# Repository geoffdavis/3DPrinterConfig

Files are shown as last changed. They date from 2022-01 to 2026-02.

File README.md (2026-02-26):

# 3DPrinterConfig

My 3D Printers Configuration backup.

## Active Printers

| | [Voronica](voronica) | [Hodad](hodad) |
|---|---|---|
| **Model** | Voron 2.4 350mm (FYSETC kit, 2.4R2 mods) | Voron v0.2r1 (Formbot kit) |
| **Mainboard** | FYSETC Spider 2.2 | BTT SKR Pico |
| **Toolhead** | Mellow SB2040 (CAN) | BTT EBB36 (CAN) |
| **Hotend** | Slice Mosquito Magnum | E3D Revo Voron |
| **Firmware** | [Klipper](https://www.klipper3d.org/) | [Klipper](https://www.klipper3d.org/) |
| **Web UI** | Fluidd / Mainsail | Mainsail |

## Retired Printers

| [MPMD](mpmd) | [Pruscilla](pruscilla) | [Smurf](smurf) | [Limewire](limewire) |
|---|---|---|---|
| Monoprice MiniDelta (stock board) | Prusa i3 MK3S (sold) | Monoprice MiniDelta w/ SKR Pico (cannibalized) | Rook MK1 (retired) |

## Guide

This firmware repo is based loosely on [willngton/3DPrinterConfig](https://github.com/willngton/3DPrinterConfig).

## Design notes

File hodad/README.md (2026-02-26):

# Hodad - Voron v0.2r1

## Overview

* Formbot Voron v0.2R1 kit.
* BTT SKR Pico mainboard
* BTT EBB36 CAN toolhead
* Revo Voron hotend with higher watt heater
* LDO Orbiter 2.0 extruder with ministealthorbiter toolhead
* Mainsail web UI
* Raspberry Pi 4 (BTT Pi from kit died)

## Modifications

* [EBB36 CAN toolhead][ebb36]
* Daylight on a matchstick, using Pico hotend heater port
* Revo VORON with higher watt heater
* Full-width [DIN rail mount][DIN-mount] for Raspberry Pi, SKR Pico, and Mellow Fly UTOC
* DS18B20 one-wire thermistor hooked up to BTT Pi to work around lack of extra Analog thermistor ports on the SKR Pico (no longer necessary with EBB36 but it's already installed.)
* Mapleleafmaker's [Stealth handles][stealth-handles] on the sides
* loicloic's [Voron V0/V0.1/V0.2 Compact Handles][compact-handles] - single one only, on front of tophat to help open it.
* Mapleleafmaker's Daylight on a [Matchstick diffusers][matchstick-diffusers]
* Mapleleafmaker's [Upper Rear Bowden Inlet for BTT SFS 2.0](https://www.printables.com/model/408745-v0-upper-rear-bowden-inlet-urbi)
* MandicReally's [Voron Hex Mid panel][mr-hex-mid-panel]
* LDO Orbiter 2.0 extruder with ministealthorbiter toolhead
* Raspberry Pi 4 instead of BTT Pi

## Notes

I nuked the Neopixel on the SKR Pico, but the digital IO pin still works and external neopixels connected to the 3-pin connector seem to work fine.

The magnets that ship with the Formbot kit are not strong enough to hold the door closed through all of the foam and plastic between them. I had some stronger ones that _just_ barely hold the door closed now.

The BTTPi died - several USB ports are fried, the mini CAN bridge seems to have flaked out. Using a RPi4 now. See also my old [notes for working with the BTT Pi.](docs/BTT_Pi.md)

## Links

* [Ballistic Tech's very helpful docs](https://github.com/SrgntBallistic/Formbot-V0)
* [Helpful build log](https://www.teamfdm.com/forums/topic/2178-my-first-voron-v02r1-formbot-kit/)

## Procedures

### Auto-hotspot

For taking the printer for a walk.

Source: [Raspberry Pi Auto-hotspot script](https://www.raspberryconnect.com/projects/65-raspberrypi-hotspot-accesspoints/183-raspberry-pi-automatic-hotspot-and-static-hotspot-installer)

Credentials are here: https://start.1password.com/open/i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

### Firmware updates

See [Firmware Update](docs/Firmware_Update.md) docs for instructions on how to update Klipper on this thing.

### Bed leveling

The front-panel menu has a bed-leveling routine on it. It's a manual `bed_screws_adjust` process.

### Bed Z offset

```gcode
G28
G1 X55 Y55 F6000
Z_ENDSTOP_CALIBRATE
```

[ebb36]: https://github.com/bigtreetech/EBB
[DIN-mount]: https://www.printables.com/model/381062-voron-v01-v02-din-rail-board-mounting-system
[stealth-handles]: https://www.printables.com/model/481575-v0-stealth-handles
[compact-handles]: https://www.printables.com/model/108428-voron-v0v01v02-compact-handles
[matchstick-diffusers]: https://www.printables.com/model/408214-matchstick-diffusers
[mr-hex-mid-panel]: https://thangs.com/designer/MandicReally/3d-model/Voron%20Hex%20Mid%20Panel%20-%20Accent%20your%200.2%21-960156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

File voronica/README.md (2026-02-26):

# Voronica - Voron 2.4 350mm

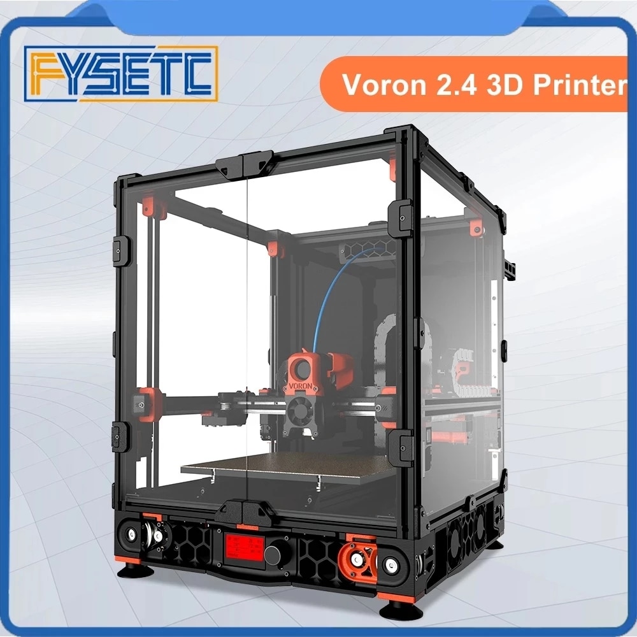
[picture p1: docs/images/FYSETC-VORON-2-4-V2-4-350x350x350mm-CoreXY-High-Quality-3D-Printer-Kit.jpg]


FYSETC Voron 2.4 Kit with 2.4R2 mods applied. Slice Mosquito Magnum hotend, option to switch to Revo. SB2040 CAN bus toolhead.

## Overview

* FYSETC Spider 2.2 mainboard (USB-CAN bridge mode)
* Mellow SB2040 CAN bus toolhead
* Slice Mosquito Magnum hotend (Revo V6 alternate)
* Bondtech CHT nozzles
* Happy Hare MMU2S multi-material unit
* Fluidd / Mainsail web UI

## Modifications

* Slice Mosquito Magnum with Bondtech CHT nozzles
* Alternate - E3D Revo V6 option
* [Mellow RP2040 CAN bus toolhead](CANBUS/SB2040/)
* [FYSETC CAN-bus Expander for Spider](https://www.fysetc.com/products/fysetc-canbus-expander-module-for-spider-board)
* Finger ducting in wiring bay [similar to LDO kit](https://docs.ldomotors.com/en/voron/voron2/wiring_guide_rev_c)
* Parts-binned filtered AC inlet - Interpower 83510031. I designed a [custom skirt to hold it](STL/Voron%20Power%20Inlet%20-%20Interpower%20Filtered/README.md).

## Electronics Bay

Here's the electronics bay as of October of 2023.

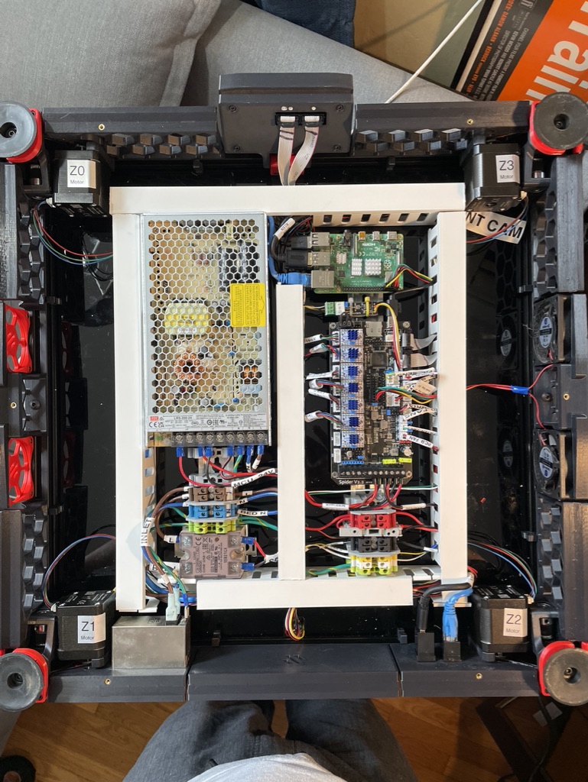
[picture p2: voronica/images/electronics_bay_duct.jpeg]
Bottom Electronics Bay with finger ducting


### Mainboard

FYSETC Spider 2.2

Rear view of the Spider board showing the pin mapping to the MCU:

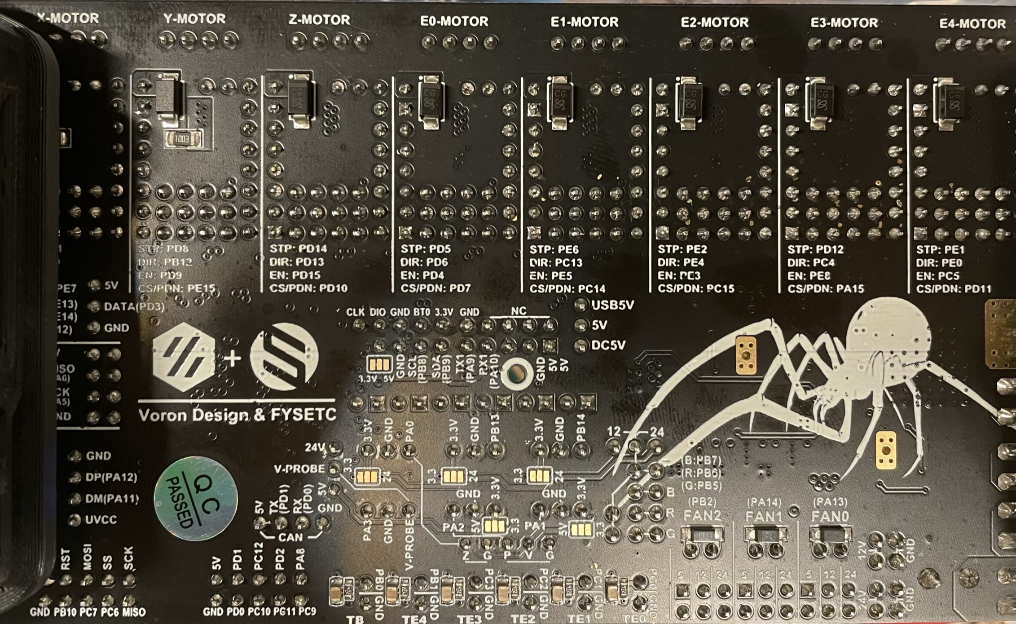
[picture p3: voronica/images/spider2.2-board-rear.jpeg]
FYSETC Spider 2.2 Mainboard Rear


There's a [mapping file of pins to symbolic names](klipper/spider_aliases.cfg) in the klipper configuration.

## Notes

Parts all printed on Pruscilla.

## Links

* [Klipper Spider Config](https://github.com/VoronDesign/Voron-2/blob/Voron2.4/firmware/klipper_configurations/Spider/Voron2_Spider_Config.cfg)
* [Klipper Install and Update Helper](https://github.com/th33xitus/kiauh)
* [FYSETC Voron 2 Repo](https://github.com/FYSETC/FYSETC-Voron-2)
* [FYSETC Kit BOM](https://github.com/FYSETC/FYSETC-Voron-2/blob/main/BOM.md)
* [FYSETC Spider Pinout](https://github.com/FYSETC/FYSETC-SPIDER/blob/main/Spider_V2.2_Pinout.pdf)
* [Voron Sourcing Guide](https://vorondesign.com/sourcing_guide?model=V2.4)
* [Mellow SB2040 install](https://www.teamfdm.com/forums/topic/851-install-canboot-on-sb2040/#comment-5785)

## Procedures

### Toolhead changes

When replacing the hotend, the effective difference between the nozzle probe point and the TAP sensor can change. This was noted when replacing the Printables version of the Mosquito hotend holder with the Bondtech one that Slice recommended.

Do this with the `PROBE_CALIBRATE` command.

### Gantry maintenance

During initial assembly, plain old loctite Blue thread locker was used, but somewhat inconsistently. Several bolts worked their way loose as a result and the gantry got racked a bit, and the Z axis bearings came loose.

The bolts were replaced and VC3 thread-locker (as recommended by Annex Engineering) was applied to all of the bolts in the gantry.

#### De-racking and squaring

Following the procedures detailed in the Voron [V2 Gantry Squaring](https://docs.vorondesign.com/build/mechanical/v2_gantry_squaring.html) documentation, I worked through reassembling the frame.

One problem noted was that the front idler bolts holding the pulleys were a bit loose, and this was adding mechanical noise. This is the big vertical bolt in the idler. The A side in particular was very loose.

#### Belt tensioning

Fiddling with belt tension is best done with a relative tension gauge, followed by `BELTS_SHAPER_CALIBRATION`

Per notes above, the idler pulley bolts in the front adjustable idlers need to be snug. Otherwise, weird vibrations result that can't be backed out with belt tension.

### Firmware updates

See [Firmware Update](docs/Firmware_Update.md) docs for instructions on how to update Klipper on this thing.

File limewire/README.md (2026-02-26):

# Limewire (RETIRED)

## About

Rook Mk1 with take-offs from Voron v0 and the MPMD. **Retired.**

## Components

* SKR Pico
* Raspberry Pi 3
* Motors from MPMD
* Power supply: Meanwell 150 Watt from formbot kit
* Bed: from Formbot v0 kit
* Bearings, rails: West3D Rook Kit

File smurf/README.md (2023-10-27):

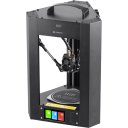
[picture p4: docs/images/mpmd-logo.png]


# MPMD "Smurf"

Monoprice MiniDelta v1 2019-era with the higher resolution stepper motors.
Converted to an SKR Pico 1.0 with a RPi 3
<br />
<br />

## Modifications

* Binder Clip Bed Mod
* Wham-Bam Flex Build plate
* Crap catchers on towers
* Stiffer spring rate extruder - CR-10 clone
* Klipper Firmware
* E3D Revo hotend with custom effector based on [ksihota's MPMD E3D V6 Effector](https://www.thingiverse.com/thing:4855333), modified for Revo micro heatsing
* SKR Pico 1.0 Main board
* Waveshare 4.3 inch DSI touchscreen for raspberry pi
* higher wattage power supply in raised base, [slobrohim's Monoprice Mini Delta Power Supply Base](https://www.thingiverse.com/thing:4786403). Had to attack it with some plastic cutters to get the raspberry pi to fit. Using the Meanwell LRS-150-12 instead of slobrohim's recommended LRS-150-24, as I didn't want to upgrade the heater pad on the bed to 24VDC. It's a small enough printer that I don't see the need to go 24V, and this way I can print off a car battery if I want later.
* BTT Smart Filament sensor
* [LED ring light at top of case.](https://www.thingiverse.com/thing:4284397) run off of the SKR Pico Neopixel bus.

## Notes

I could not get the stock optical end-stops to work at all. I may have nuked them by sending them 5V instead of 3.3 v. I tried another set from the MP Mini Delta V2 and had similar lack of luck.

Attemped using the TMC2209 virtual endstops with the printed endstop replacements from https://www.prusaprinters.org/prints/113166-mpmd-frame-mods

Found that it wasn't as reliable as I'd like - even with endstop phase turned on, tuning the virtual endstops was an exercise in frustration. Switched to Lerge optical endstops using custom parts found on the Facebook group for the MPMD:

* https://www.facebook.com/groups/mpminideltaowners/permalink/3501827253166069/
* https://www.facebook.com/groups/mpminideltaowners/permalink/3500216336660494/
* https://www.facebook.com/groups/mpminideltaowners/permalink/3487387884610006/

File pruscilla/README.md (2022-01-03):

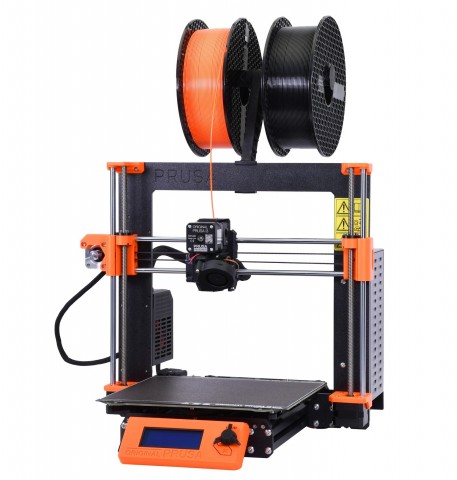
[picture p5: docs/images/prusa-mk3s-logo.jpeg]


# Pruscilla

Pruscilla i3 MK3S
<br />
<br />

## Modifications

* MK3S+ hotend
* "Custom" fried fan port on Einsy
* MMU2S
* PrintedSolid Enclosure
* Pi4 with TFT and Octoprint/Octodash

# Guides

## Prusa Firmware with Pin Remap

I keep somehow frying the hotend thermistor port on multiple Einsy rambo boards. There's a way to remap to an unused port by custom compiling your own firmware.

### Requirements:

* Debian/Ubuntu Linux x86_64. Doesn't work on MacOS, doesn't work on Raspbian

* Ubuntu VM (I use the one on my main workstation, Obelisk)

* Check out [firmware] repository.

### Build

#### Step 1 - checkout/update source
*NOTE* You might need to `git clean -dxf` an existing checkout in order to get the build to work right.

#### Step 2 - Set up the firmware variant and modify pin definitions

##### Step 2a: Set the firmware variant
Set the firmware variant to the correct one.

cp Firmware/variants/

##### Step 2b: Change the pin definitions
Apply the following diff, swapping TEMP_0_PIN and TEMP_1_PIN. TEMP_0_PIN should be 0, while TEMP_1_PIN should be 1.

```
geoff@obelisk-ubuntu:~/src/Prusa-Firmware$ git diff
diff --git a/Firmware/pins_Einsy_1_0.h b/Firmware/pins_Einsy_1_0.h
index b3841a59..74de5ea9 100755
--- a/Firmware/pins_Einsy_1_0.h
+++ b/Firmware/pins_Einsy_1_0.h
@@ -59,10 +59,12 @@
 #define TEMP_BED_PIN         2 //A2
 
 #define HEATER_0_PIN         3 //PE5
-#define TEMP_0_PIN           0 //A0
+//#define TEMP_0_PIN           0 //A0
+#define TEMP_0_PIN           1 //A1 as A0 is fried
 
 #define HEATER_1_PIN        -1
-#define TEMP_1_PIN           1 //A1
+//#define TEMP_1_PIN           1 //A1
+#define TEMP_1_PIN           0 //A0 (this pin is unused)
 
 #define HEATER_2_PIN        -1
 #define TEMP_2_PIN          -1
```

#### Step 3 - build
Run `./build.sh`

Resulting bin file is in `lang/firmware.hex`

[firmware]: https://github.com/prusa3d/Prusa-Firmware.git

#### Step 4 - Upload the file

You can do this from the octoprint host. Use `scp` to put it somewhere on octoprint:

```
scp lang/firmware.hex pi@pruscilla:
```

Then, use `avrdude` to upload it from the octoprint host:

```
avrdude -v -p atmega2560 -c wiring -P /dev/ttyACM0 -b 115200 -D -U flash:w:firmware.hex:i
```

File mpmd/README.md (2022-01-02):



## MPMD

Monoprice MiniDelta v1 2019-era with the higher resolution stepper motors.
<br />
<br />

### Modifications

* Binder Clip Bed Mod
* Borosilicate Glass Bed
* Crap catchers on towers
* Stiffer spring rate extruder
* Klipper Firmware using stock mainboard

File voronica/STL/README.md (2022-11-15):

# STLs

Custom STL files used during the build.

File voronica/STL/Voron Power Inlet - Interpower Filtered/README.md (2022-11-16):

Voron 2.4 Power inlet skirt for Interpower filtered power inlet
===

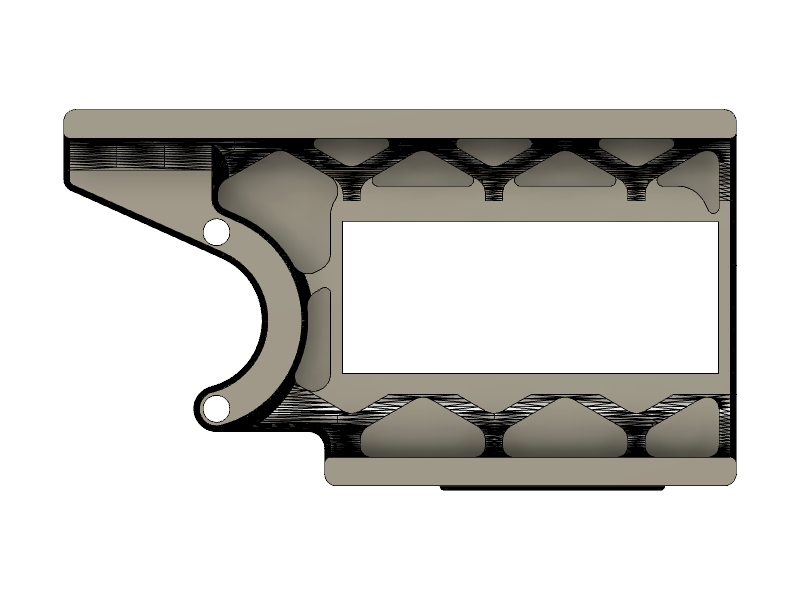
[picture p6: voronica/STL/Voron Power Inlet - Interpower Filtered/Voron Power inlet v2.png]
Voron Interpower power inlet skirt v2


Application
---

Fits an [Interpower](https://interpower.com) panel-mount snap fit IEC power inlet.

Designed for P/N [83510031](https://www.interpower.com/cgi-bin/ic.cgi/p35form.p?w_part=83510031)

Should also fit P/N [83510071](https://www.interpower.com/cgi-bin/ic.cgi/p35form.p?w_part=83510071)

License
---

GPLv3 (same as upstream Voron 2.4 STLs)
See [LICENSE](LICENSE) for details.

Author
---

Geoff Davis <geoff@geoffdavis.com>

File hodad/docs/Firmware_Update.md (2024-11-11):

# Hodad Klipper Firmware Update Procedures

## SKR Pico

This MCU is connected via UART, updates must be done over USB.

### Step 1: Get unit in DFU mode
Connect USB-A-M to USB-C-M cable between host and MCU
Install boot jumper, then press reset button. Boot jumper is in the middle of the board, to the right of the power LED as mounted in the printer (closer to the TMC driver heatsink with the bigtreetech logo)
Verify that the device shows up in lsusb:

```
pi@hodad:~/klipper $ lsusb | grep RP2
Bus 001 Device 015: ID 2e8a:0003 Raspberry Pi RP2 Boot
```

### Step 2: Build firmware

Per [https://github.com/bigtreetech/SKR-Pico/tree/master/Klipper] set:
* Enable extra low-level configuration options
* Micro-controller Architecture = `Raspberry Pi RP2040`
* Communication interface = `Serial (on UART0 GPIO1/GPIO0)`

Run `make clean`
Run `make -j3`

### Step 3: Flash firmware

*NOTE* this requires that the unit be placed in DFU mode per step 1, above.

Run `make flash FLASH_DEVICE=2e8a:0003`

### Step 4: Remove boot jumper

Remove the boot jumper to the right of the power LED. Optionally, press the reset button (white button towards the top of the board as mounted in the printer)

## v0 Display board

This unit is connected via USB.

Docs: [https://github.com/VoronDesign/Voron-Hardware/blob/master/V0_Display/Documentation/Setup_and_Flashing_Guide.md]

### Step 1 - DFU mode

Install the boot jumper and reset the board. This will put the board into DFU mode.

The boot jumper is located on the top rear of the v0 display PCB, and is a real pain to access.

1. Remove the bottom panel - 2mm hex driver, round or square
2. Remove the v0 display with a round head 2 mm hex driver
3. install the boot jumper
4. Press reset
5. Verify it shows up in `lsusb`
```
pi@hodad:~/klipper $ lsusb | grep DFU
Bus 001 Device 022: ID 0483:df11 STMicroelectronics STM Device in DFU Mode
```

### Step 2 - Build firmware

This controller has very limited flash memory, and a full-blow Klipper instance won't fit. Be sure to uncheck most of the Optional features as shown below.

Firmware settings:

* Enable extra low-level configuration options
* Micro-controller Architecture: `STMicroelectronics STM32`
* Processor model: `STM32F042`
* Bootloader offset: `No bootloader`
* Clock reference: `internal clock`
* Communication interface `USB (on PA9/PA10)`
* Optional features:
  a. Check `Support GPIO "bit-banging" devices`
  b. Check `Support LCD devices`
  c. Check `Support external sensor devices`
  d. Uncheck `Support lis2dw 3-axis accelerometer`
  e. Uncheck `Support ldc1612 eddy current sensor`
  f. Uncheck `Support HX711 and HX717 ADC chips`
  g. Uncheck `Support ADS 1220 ADC chip`
  e. Uncheck `Support software based I2C "bit-banging"`
  f. Check `Support software based SPI "bit-banging"`

Run `make clean`

### Step 3 - flash firmware

Run `make flash FLASH_DEVICE=0483:df11`

### Step 4 - Remove boot jumper

Remove the boot jumper and press the reset button

Verify that you now see one or more stm32f042x6 devices in lsusb, and that `/dev/serial/by-id/usb-Klipper_stm32f042x6_05001A000643564E32313720-if00` appears in `/dev/serial/by-id`

h5. Re-install display and bottom cover

Curse at no-drop nuts that still drop anyway.

This is best done with the printer completely inverted so that the nuts in the extrusion don't keep sliding around.

## Klipper Expander

Very similar to the V0 Display, same controller. Same recommended firmware settings.

[https://github.com/VoronDesign/Voron-Hardware/blob/master/Klipper_Expander/Documentation/Setup_and_Flashing_Guide.md]

### Step one - DFU mode

1. Install the boot jumper. Boot jumper is between the USB port and the DC input terminals.
2. Press the reset button. The reset button is next to the "n" in the "Voron Design" silkscreen.
3. Verify it shows up in `lsusb`
```
pi@hodad:~/klipper $ lsusb | grep DFU
Bus 001 Device 022: ID 0483:df11 STMicroelectronics STM Device in DFU Mode
```

*NOTE* as this is the same chip as the V0 display, make sure you only have one device in DFU mode at a time.

### Step two - compile firmware

Firmware settings (identical to V0 Display):

* Enable extra low-level configuration options
* Micro-controller Architecture: `STMicroelectronics STM32`
* Processor model: `STM32F042`
* Bootloader offset: `No bootloader`
* Clock reference: `internal clock`
* Communication interface `USB (on PA9/PA10)`
* Optional features:
  a. Check `Support GPIO "bit-banging" devices`
  b. Check `Support LCD devices`
  c. Check `Support external sensor devices`
  d. Uncheck `Support lis2dw 3-axis accelerometer`
  e. Uncheck `Suppert software based I2C "bit-banging"`
  f. Check `Support software based SPI "bit-banging"`

### Step 3 - flash firmware

Run `make flash FLASH_DEVICE=0483:df11`

### Step 4 - remove jumper and reset board

Verify no devices in DFU mode show in the `lsusb` output

Verify that the MCU shows up as `/dev/serial/by-id/usb-Klipper_stm32f042x6_08002300134330534E373720-if00`

## EBB36 Can Toolhead board

This unit has [katapult](https://github.com/Arksine/katapult) (formerly "Can-boot") installed. KB-3D has [decent instructions for installing katapult on a fresh board](https://wiki.kb-3d.com/en/home/btt/voron/BTT_EBB36), though you will need to replace all references to `Can-boot` with `katapult`.

NOTE: once `katapult`/`Can-boot` is installed, the device will no longer show up in the output of `lsusb` if you connect it directly to the Pi with a USB cable. It will show up however if you put the device into DFU mode.

The instructions below assume that you've already installed `katapult` and are just upgrading the `klipper` firmware.

### Step 1 - Verify CAN is working

Press the reset button on the back of the EBB36 toolhead board.

Run the following:

```
~/CanBoot/scripts/flash_can.py -i can0 -q
```

You should see output similar to:

```
pi@hodad:~ $ ~/katapult/scripts/flash_can.py -i can0 -q
Resetting all bootloader node IDs...
Checking for Katapult nodes...
Detected UUID: 12676b53cab4, Application: Klipper
Query Complete
```

Step 2: Compile firmware

```
cd ~/klipper
make menuconfig
```

Firmware settings:

* `Enable extra low-level configuration options`
* Micro-controller Architecture `STMicroelectronics STM32`
* Processor model: `STM32G0B1`
* Bootloader: `8KiB bootloader`
* Clock Reference: `8 MHz crystal`
* Communication interface: `CAN bus (on PB0/PB1)`
* CAN bus speed: `1000000` -- note that this must match setting in `/etc/network/interfaces.d/can0`
* GPIO pins to set at micro-controller startup: none

```
make clean
make -j3
```

### Step 3: Flash firmware over canbus

The UUID of the board is `2aab98198ff0` (November 2024 was `12676b53cab4` originally)

```
python3 ~/katapult/scripts/flash_can.py -i can0 -f ~/klipper/out/klipper.bin -u 2aab98198ff0
```

If all goes well, it should look like this:

```
python3 ~/katapult/scripts/flash_can.py -i can0 -f ~/klipper/out/klipper.bin -u 2aab98198ff0
Sending bootloader jump command...
Resetting all bootloader node IDs...
Attempting to connect to bootloader
Katapult Connected
Protocol Version: 1.0.0
Block Size: 64 bytes
Application Start: 0x8002000
MCU type: stm32g0b1xx
Verifying canbus connection
Flashing '/home/pi/klipper/out/klipper.bin'...

[##################################################]

Write complete: 14 pages
Verifying (block count = 427)...

[##################################################]

Verification Complete: SHA = F836B5FC5E1BD91779D80950095C73C06F06593C
Flash Success
```

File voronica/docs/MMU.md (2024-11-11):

# MMU Notes

## Purge volumes with CLEAN_NOZZLE

From Voron Discord #ercf_questions:

Dendrowen (mr. Blobifier) — 01/06/2024 11:57 AM
Yeah, I'm having problems with the retraction of filametrix, so I only retract 15mm which means around 40mm is still there. I have a purge command that purges 40mm + the flushing volumes

CLEAN_NOZZLE FINAL_RETRACT={retraction_length[0]} PURGE_LEN={40 + first_flush_volume + second_flush_volume} 

I use OrcaSlicer and have my flushing multiplier set to 0.40.

https://github.com/moggieuk/Happy-Hare/blob/variables/doc/gcode_preprocessing.md

https://github.com/moggieuk/Happy-Hare/blob/main/doc/slicer_setup.md#---start-g-code

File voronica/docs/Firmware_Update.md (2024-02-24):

# Voronica Firmware Update Procedures

One of the annoying things about Klipper is that updating the MCUs isn't an easy task. Each MCU has to be compiled individually, and this can clobber your firmware configuration files if you're not careful.

In the klipper-build directory, I keep some of the menuconfig output for the various MCUs.

## Spider

Board must be in DFU in order to flash.

### Step one - stop klipper
1. `sudo service klipper stop`

### Step two - put Spider board in DFU mode

1. Install jumper between BT0 and 3.3V - USE PLASTIC TWEEZERS or power down printer, or be a hero and use long metal needlenose and try not to short anything.
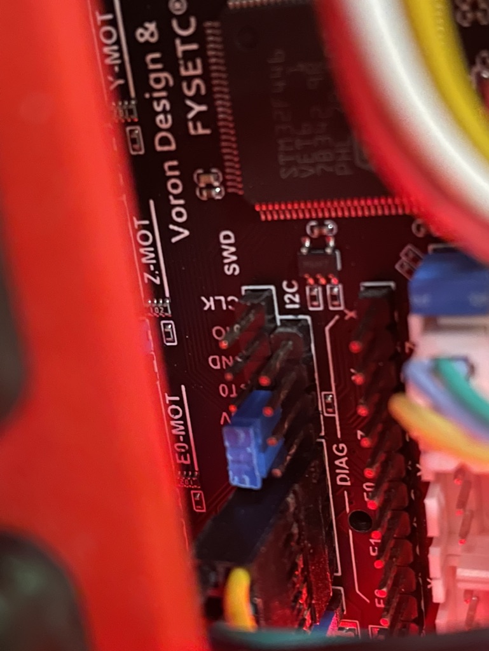
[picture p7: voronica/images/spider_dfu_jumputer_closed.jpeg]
Jumper Closed

1. Press reset button on right hand side by Pi (below white zip tie in below picture)
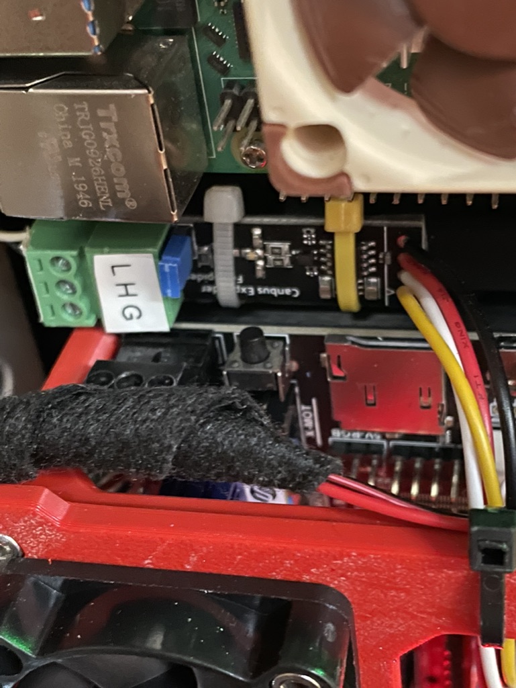
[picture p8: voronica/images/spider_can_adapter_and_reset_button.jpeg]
Reset button

1. Verify the spider shows up in `lsusb` output. Should be something like:

    ```none
    ~/klipper  ‹master*› $ lsusb | grep DFU
    Bus 001 Device 005: ID 0483:df11 STMicroelectronics STM Device in DFU Mode
    ```

### Step three - build and flash klipper

1. Perform the build and flash.

    ```bash
    cd ~/klipper
    FLASH_DEVICE="0483:df11"
    KCONFIG_DIR="${HOME}/printer_data/config/klipper-build"
    _kc="${KCONFIG_DIR}/config.spider"
    make clean KCONFIG_CONFIG="${_kc}"
    make menuconfig KCONFIG_CONFIG="${_kc}"
    make -j4 KCONFIG_CONFIG="${_kc}"
    make flash FLASH_DEVICE="${FLASH_DEVICE}" KCONFIG_CONFIG="${_kc}"
    ```

    a. If the settings get clobbered, use:

      * Enable extra low-level configuration options
      * Microcontroller Arch: `STMicroelectronics STM32`
      * Processor model: `STM32F446`
      * Bootloader offset: `32KiB bootloader`
      * Clock Reference: `12 MHz crystal`
      * Communication interface: `USB to CAN bus bridge (USB on PA11/PA12)`
      * CAN bus interface: `CAN bus (on PD0/PD1)`
      * CAN bus speed 1000000 (1Mbit, defaults to 500000)
      * GPIO Pins to set at micro-controller startup: NONE (make sure it's empty)

### Step four - take board out of DFU mode

1. Remove jumper - USE PLASTIC TWEEZERS
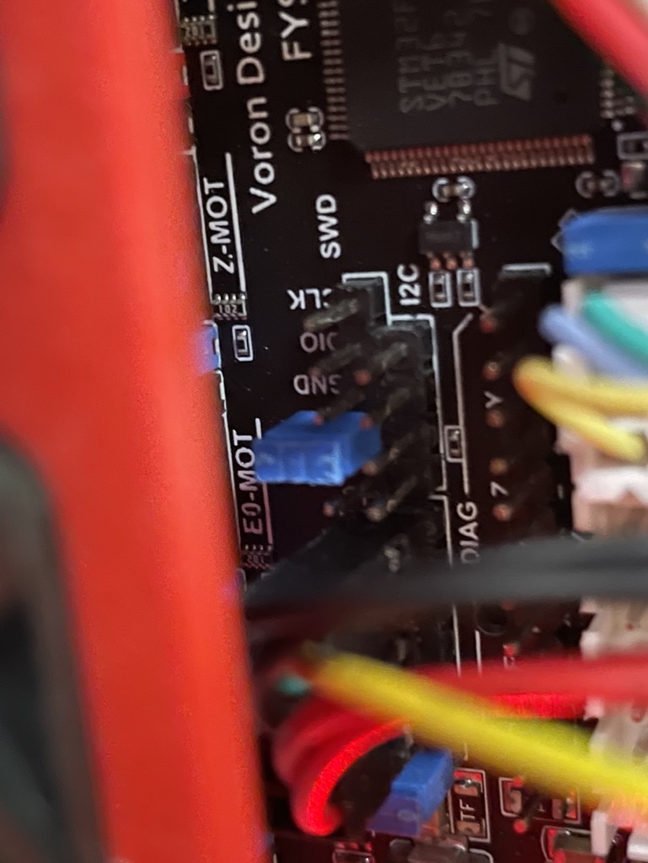
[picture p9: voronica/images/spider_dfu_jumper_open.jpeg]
Jumper open
Jumper in open position: 
1. Press reset button (below white zip tie in picture)
Reset button
1. Verify board shows up in `lsusb` output again

    ```none
    ~/klipper  ‹master*› $ lsusb | grep CAN
    Bus 001 Device 008: ID 1d50:606f OpenMoko, Inc. Geschwister Schneider CAN adapter
    ```

### Step five - restart Klipper

1. Start klipper

NOTE: depending on the state of the USB to CAN adapter, the SB2040

## SB2040 Toolhead via CanBoot

This toolhead was originally configured using the CanBoot instructions from this document: [SB2040 and the curious case of disappearing firmware](https://docs.google.com/document/d/1yaRNuQxDxqgijE8YeJ2r9tUZgJZ4tXXjmrAiFyAfsek/edit)

Once installed, the CanBoot firmware rarely, if ever, needs to be updated again.

NOTE: to get the SB2040 into DFU mode, you need to stop klipper first, then power cycle the toolhead. The asiest way to do that at the moment is to pull the fuse in the underside electronics bay.

### Step One - stop klipper

1. `sudo service klipper stop`

### Step Two - get board into DFU mode

1. Power cycle toolhead by opening and closing the fuse panel on the bottom.
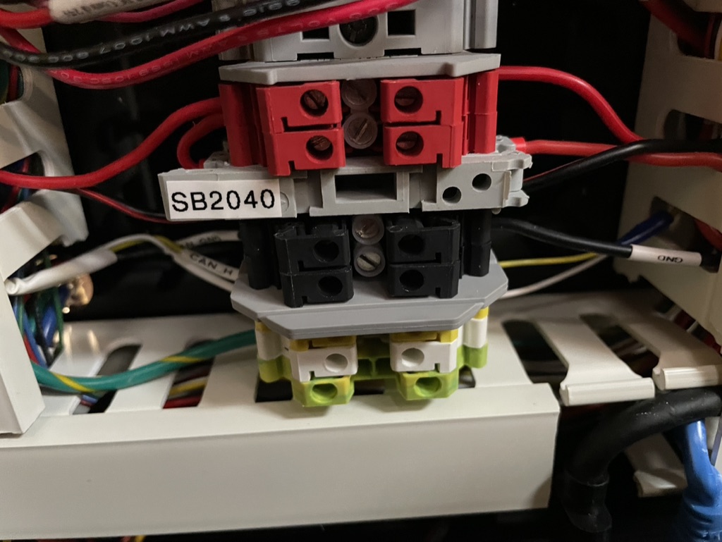
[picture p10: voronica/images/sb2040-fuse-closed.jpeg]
SB2040 Fuse
  Closed fuse: 
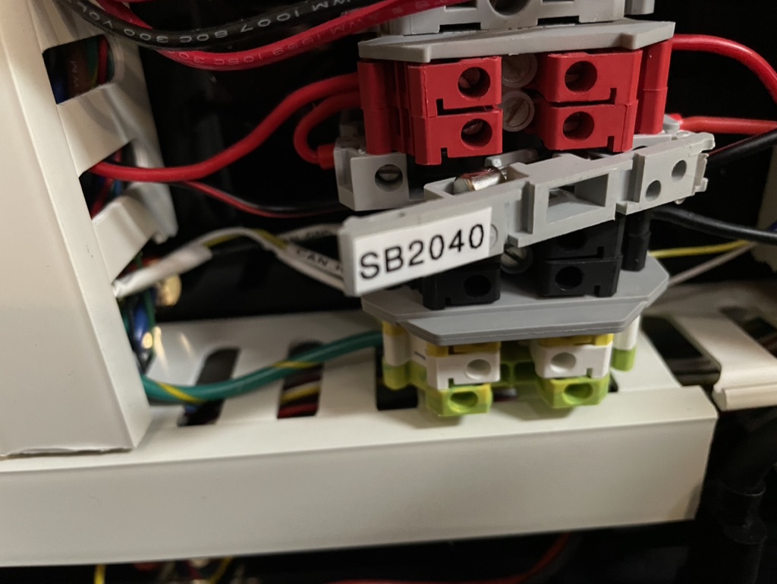
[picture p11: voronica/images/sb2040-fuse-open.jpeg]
SB2040 Fuse Open
  Open fuse: 

### Step 3 - Build and Flash

1. Find the CAN ID:

    ```bash
    cd ~/CanBoot
    ../klippy-env/bin/python ../klipper/scripts/canbus_query.py can0
    ```

    Should show something like:

    ```none
     ~/CanBoot/ [master] ../klippy-env/bin/python ../klipper/scripts/canbus_query.py can0
    Found canbus_uuid=f6f9ce8939ef, Application: Klipper
    Total 1 uuids found
    ```
1. Perform the build and flash.

    ```bash
    cd ~/klipper
    CANBUS_UUID=f6f9ce8939ef
    KCONFIG_DIR="${HOME}/printer_data/config/klipper-build"
    _kc="${KCONFIG_DIR}/config.sb2040-canboot"
    make clean KCONFIG_CONFIG="${_kc}"
    make menuconfig KCONFIG_CONFIG="${_kc}"
    make -j4 KCONFIG_CONFIG="${_kc}"
    ./lib/canboot/flash_can.py -u $CANBUS_UUID -v -f ./out/klipper.bin
    ```

    a. If the settings get clobbered, use:
      * Extra options: enabled
      * Microcontroller Arch: `Raspberry Pi RP2040`
      * Bootloader offset: `16KiB bootloader`
      * Flash chip W25Q080 with CLKDIV 2
      * Communication interface `CAN bus`
      * CAN bus speed: `1000000` (1Mbit, defaults to 500000)
      * CAN RX gpio number: `4`
      * CAN TX gpio number: `5`
      * GPIO pins to set at startup: `gpio24`

### Step 4 - Restart Klipper
1. Start klipper and make sure that the system sees the MCU: `sudo service klipper start`

## Raspberry Pi host

This MCU lets you trigger relays and other GPIOs. I'm not currently using any of that functionality, but I am using it for the host load average calculations and other side benefits.

### Step 1 - Stop Klipper

1. Stop klipper `sudo service klipper stop`

### Step 2 - Build and flash
1. Perform the build and flash.

    ```bash
    cd ~/klipper
    KCONFIG_DIR="${HOME}/printer_data/config/klipper-build"
    _kc="${KCONFIG_DIR}/config.rpi"
    make clean KCONFIG_CONFIG="${_kc}"
    make menuconfig KCONFIG_CONFIG="${_kc}"
    make -j4 KCONFIG_CONFIG="${_kc}"
    make flash KCONFIG_CONFIG="${_kc}"
    ```

    a. If the settings get clobbered, use:

      * Microcontroller Arch Linux process

### Step 3 - Restart Klipper

1. Start klipper `sudo service klipper start`

## TinyFan

Extra fan controller - https://github.com/Gi7mo/TinyFan

### Step 1 - DFU Mode

1. Stop klipper `sudo service klipper stop`
1. Press boot and reset simultaneously on the tinyfan rp2040 daughterboard.
    You should now see the following in `lsusb` output:
    ```Bus 001 Device 018: ID 2e8a:0003 Raspberry Pi RP2 Boot```

### Step 2 Perform the build

    ```bash
    cd ~/klipper
    KCONFIG_DIR="${HOME}/printer_data/config/klipper-build"
    _kc="${KCONFIG_DIR}/config.tinyfan"
    make clean KCONFIG_CONFIG="${_kc}"
    make menuconfig KCONFIG_CONFIG="${_kc}"
    make -j4 KCONFIG_CONFIG="${_kc}"
    ```

    a. If the settings get clobbered, use:

      * Enable extra low-level configuration options
      * Micro-controller Architecture: `Raspberry Pi RP2040`
      * Flash chip: `GENERIC_03H with CLKDIV 4`
      * Communication interface: `USB`
      * USB ids: leave default
      * GPIO pins at startup: EMPTY

### Step 3 - flash the device

```bash
sudo mount /dev/sda1 /mnt && \
sudo cp out/klipper.uf2 /mnt && \
sudo umount /mnt
```

### Step 4 - Reset the board

Press the reset button on the daughterboard

Verify that you can now see in `lsusb`:

```
Bus 001 Device 020: ID 1d50:614e OpenMoko, Inc. rp2040
```

### Step 5 - Restart klipper

1. Start klipper `sudo service klipper start`

## TradRack SKR Mini E3 V2.0

This device has Katapult installed, because mini sd card firmware updates are for chumps.

Katapult instructions: [https://klipper.discourse.group/t/flashing-klipper-friendly-bootloader-on-btt-skr-mini-e3-v2/10977]

### Step 1 - Stop Klipper

### Step 2 - put board in USB bootloader mode

Double press the reset button on the mainboard.

### Step 3 - Compile Klipper

```bash
cd ~/klipper
KCONFIG_DIR="${HOME}/printer_data/config/klipper-build"
_kc="${KCONFIG_DIR}/config.tr"
make clean KCONFIG_CONFIG="${_kc}" && \
make menuconfig KCONFIG_CONFIG="${_kc}" && \
make -j4 KCONFIG_CONFIG="${_kc}"
```

If the settings get clobbered, use:

* **Enable** extra low-level configuration options
* Micro-controller Architecture: `STMicroelectronics STM32`
* Bootloader offset: `8KiB bootloader` - *NOTE this is different than the Voron default of `28KiB` due to `katapult` being in place!!*
* Clock reference: `8 MHz crystal`
* Communication interface: `USB (on PA11/PA12)`
* GPIO pins: `!PA14` - Don't forget to set this, the board won't boot otherwise

### Step 4 - flash the board

Note that the device must be in bootloader mode per Step 2.

1. Run the flash command:

  ```bash
  # Below command only worked the first time with the deployer.bin
  make flash \
    KCONFIG_CONFIG="${_kc}" \
    FLASH_DEVICE=/dev/ttyACM3
  #
  # --or--
  #
  # this worked with the double-press of the reset button
  make flash \
    KCONFIG_CONFIG="${_kc}" \
    FLASH_DEVICE=/dev/serial/by-id/usb-katapult_stm32f103xe_30FFDA054E4E353717730551-if00
  ```

### Step 5 - restart klipper

1. Reset the board to get it out of DFU.
1. Start klipper: `sudo service klipper start`

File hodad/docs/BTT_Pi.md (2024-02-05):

# BigTreeTech Pi Notes

## Dallas 1-wire

* DS18B20 on BigTreeTech Pi: https://gist.github.com/mdvorak/2fccca3fa9f76f5a2e11e567797c76d6
* One-wire kernel module compilation instructions: https://github.com/pstolarz/w1-gpio-cl#readme

## BTT Pi Pins

Overflow sensors are hooked into the BTT Pi 24-pin header

| Pin # | Pin Name | Description |
| ----- | --- | --- |
| 1 | 3.3V | DS18B20 VCC |
| 3 | PC3 | N/C (reserved for ADXL Header) |
| 5 | PC0 | N/C (reserved for ADXL Header) |
| 7 | PC7 (GPIO71) | DS18B20 One-wire data |
| 9 | GND | DS18B20 Ground |
| 11 | PC14 | NC |
| 13 | PC12 | NC |
| 15 | PC10 | NC |
| 17 | 3.3V | BTT SFS2.0 VCC |
| 19 | PH7 (GPIO231) | BTT SFS2.0 Switch Sensor |
| 21 | PH8 (GPIO232) | BTT SFS2.0 Motion Sensor |
| 23 | PH6 (GPIO23) | NC |
| 25 | GND | BTT SFS2.2 GND |
| 27 | PC2 (GPIO66) | N/C (reserved for ADXL Header) |
| 29 | PC4 (GPIO68) | N/C (reserved for ADXL Header) |
| 31 | PI5 (GPIO261) | MOSFET 4 |
| 33 | PI14 (GPIO270) | MOSFET 3 |
| 35 | PC6 (GPIO70) | MOSFET 2 |
| 37 | PC15 (GPIO79) | MOSFET 1 |
| 39 | GND | MOSFET Input Ground |
| 2 | 5V | From SKR Pico 5V |
| 4 | 5V | From SKR Pico 5V |
| 6 | GND | From SKR Pico GND |
| 8 | TX | To SKR Pico RX |
| 10 | RX | To SKR Pico TX |
| 12 | PC13 | NC |
| 14 | GND | NC |
| 16 | PC11 | NC |
| 18 | PC9 | NC |
| 20 | GND | NC |
| 22 | PG13 | NC |
| 24 | PG12 | NC |
| 26 | PI9 | NC |
| 28 | PI10 (Blue, EEPROM?) | NC |
| 30 | GND | NC |
| 32 | PI6 | NC |
| 34 | GND | NC |
| 36 | PG11 | NC |
| 38 | PH4 | NC |
| 40 | PC8 | NC |

###
```none
biqu@hodad:~/3DPrinterConfig$ sudo cat /sys/kernel/debug/pinctrl/300b000.pinctrl/pinmux-pins
Pinmux settings per pin
Format: pin (name): mux_owner|gpio_owner (strict) hog?
pin 0 (PA0): device 5030000.ethernet function emac1 group PA0
pin 1 (PA1): device 5030000.ethernet function emac1 group PA1
pin 2 (PA2): device 5030000.ethernet function emac1 group PA2
pin 3 (PA3): device 5030000.ethernet function emac1 group PA3
pin 4 (PA4): device 5030000.ethernet function emac1 group PA4
pin 5 (PA5): device 5030000.ethernet function emac1 group PA5
pin 6 (PA6): device 5030000.ethernet function emac1 group PA6
pin 7 (PA7): device 5030000.ethernet function emac1 group PA7
pin 8 (PA8): device 5030000.ethernet function emac1 group PA8
pin 9 (PA9): device 5030000.ethernet function emac1 group PA9
pin 10 (PA10): device 5002c00.i2c function twi3 group PA10
pin 11 (PA11): device 5002c00.i2c function twi3 group PA11
pin 12 (PA12): device soc:pwm5@0300a000 function pwm5 group PA12
pin 64 (PC0): UNCLAIMED
pin 65 (PC1): UNCLAIMED
pin 66 (PC2): UNCLAIMED
pin 67 (PC3): UNCLAIMED
pin 68 (PC4): UNCLAIMED
pin 69 (PC5): UNCLAIMED
pin 70 (PC6): UNCLAIMED
pin 71 (PC7): GPIO 300b000.pinctrl:71
pin 72 (PC8): UNCLAIMED
pin 73 (PC9): UNCLAIMED
pin 74 (PC10): UNCLAIMED
pin 75 (PC11): UNCLAIMED
pin 76 (PC12): UNCLAIMED
pin 77 (PC13): UNCLAIMED
pin 78 (PC14): UNCLAIMED
pin 79 (PC15): GPIO 300b000.pinctrl:79
pin 80 (PC16): UNCLAIMED
pin 160 (PF0): device 4020000.mmc function mmc0 group PF0
pin 161 (PF1): device 4020000.mmc function mmc0 group PF1
pin 162 (PF2): device 4020000.mmc function mmc0 group PF2
pin 163 (PF3): device 4020000.mmc function mmc0 group PF3
pin 164 (PF4): device 4020000.mmc function mmc0 group PF4
pin 165 (PF5): device 4020000.mmc function mmc0 group PF5
pin 166 (PF6): GPIO 300b000.pinctrl:166
pin 192 (PG0): device 4021000.mmc function mmc1 group PG0
pin 193 (PG1): device 4021000.mmc function mmc1 group PG1
pin 194 (PG2): device 4021000.mmc function mmc1 group PG2
pin 195 (PG3): device 4021000.mmc function mmc1 group PG3
pin 196 (PG4): device 4021000.mmc function mmc1 group PG4
pin 197 (PG5): device 4021000.mmc function mmc1 group PG5
pin 198 (PG6): UNCLAIMED
pin 199 (PG7): UNCLAIMED
pin 200 (PG8): UNCLAIMED
pin 201 (PG9): UNCLAIMED
pin 202 (PG10): UNCLAIMED
pin 203 (PG11): UNCLAIMED
pin 204 (PG12): UNCLAIMED
pin 205 (PG13): UNCLAIMED
pin 206 (PG14): UNCLAIMED
pin 207 (PG15): GPIO 300b000.pinctrl:207
pin 208 (PG16): UNCLAIMED
pin 209 (PG17): UNCLAIMED
pin 210 (PG18): GPIO 300b000.pinctrl:210
pin 211 (PG19): UNCLAIMED
pin 224 (PH0): device 5000000.serial function uart0 group PH0
pin 225 (PH1): device 5000000.serial function uart0 group PH1
pin 226 (PH2): UNCLAIMED
pin 227 (PH3): UNCLAIMED
pin 228 (PH4): UNCLAIMED
pin 229 (PH5): UNCLAIMED
pin 230 (PH6): UNCLAIMED
pin 231 (PH7): UNCLAIMED
pin 232 (PH8): UNCLAIMED
pin 233 (PH9): UNCLAIMED
pin 234 (PH10): UNCLAIMED
pin 256 (PI0): UNCLAIMED
pin 257 (PI1): UNCLAIMED
pin 258 (PI2): UNCLAIMED
pin 259 (PI3): UNCLAIMED
pin 260 (PI4): UNCLAIMED
pin 261 (PI5): UNCLAIMED
pin 262 (PI6): UNCLAIMED
pin 263 (PI7): UNCLAIMED
pin 264 (PI8): UNCLAIMED
pin 265 (PI9): UNCLAIMED
pin 266 (PI10): UNCLAIMED
pin 267 (PI11): UNCLAIMED
pin 268 (PI12): UNCLAIMED
pin 269 (PI13): UNCLAIMED
pin 270 (PI14): UNCLAIMED
pin 271 (PI15): UNCLAIMED
pin 272 (PI16): UNCLAIMED
```

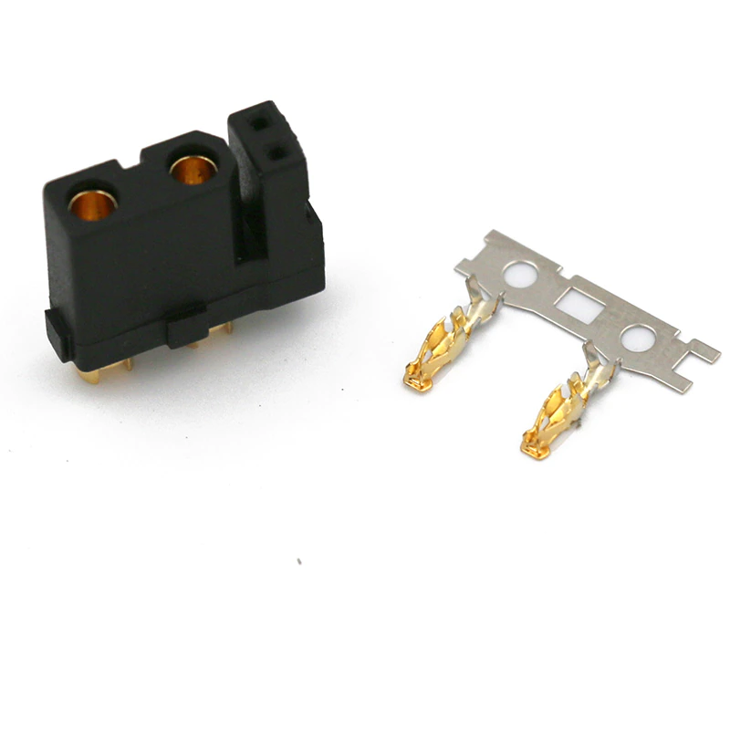
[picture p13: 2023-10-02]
voronica/CANBUS/SB2040/Ha28af9035aa1499194c98f9bcaca8fcdC.webp

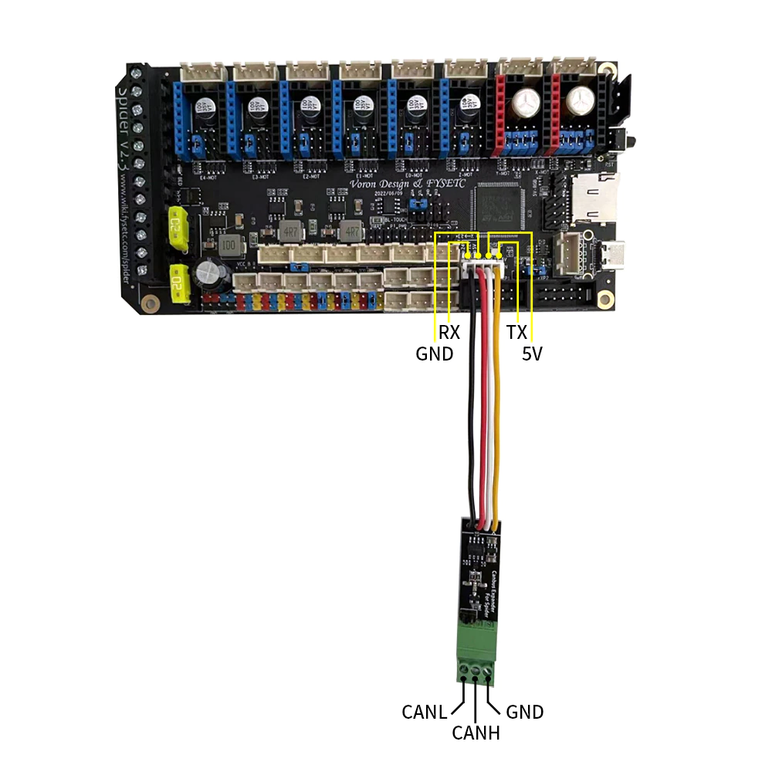
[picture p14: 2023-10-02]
voronica/CANBUS/CANBUS-Expander.webp

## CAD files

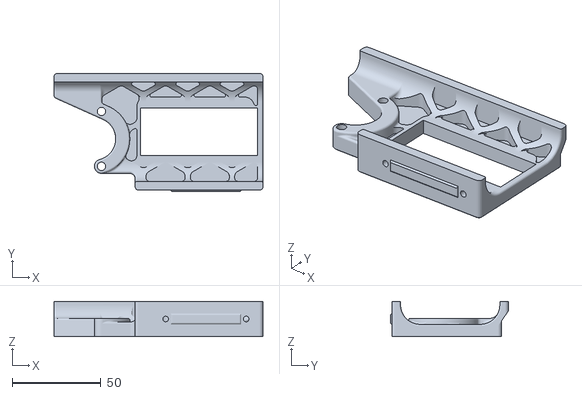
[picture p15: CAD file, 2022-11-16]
voronica/STL/Voron Power Inlet - Interpower Filtered/power_inlet_interpower_filtered.stl
118.0 x 66.8 x 20.0

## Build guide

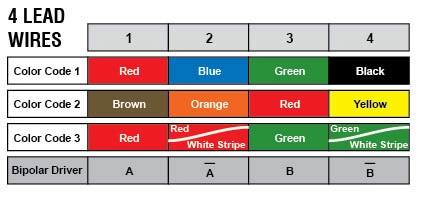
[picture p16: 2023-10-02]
voronica/docs/Stepper Motors/Wiring_4_lead_Wires_c08b9b2bf8.webp

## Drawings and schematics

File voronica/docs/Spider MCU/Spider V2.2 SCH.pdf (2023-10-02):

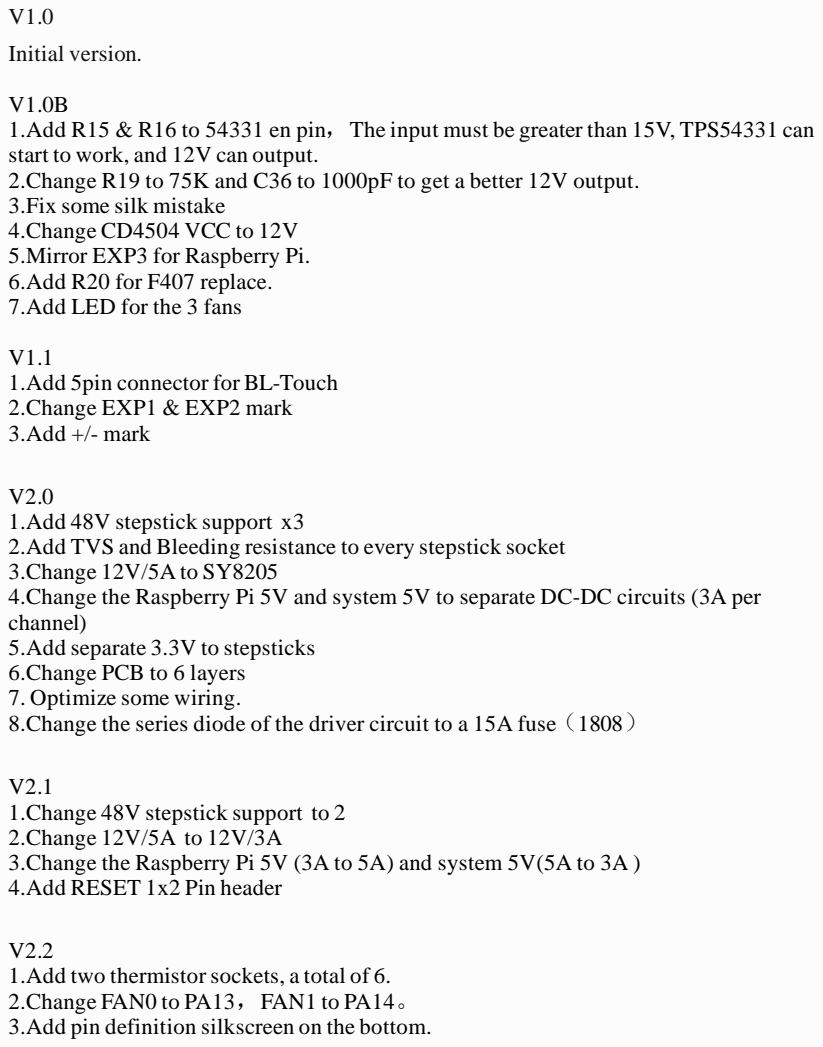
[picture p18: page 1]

1.Add R15 & R16 to 54331 en pin，The input must be greater than 15V, TPS54331 can
start to work, and 12V can output.
2.Change R19 to 75K and C36 to 1000pF to get a better 12V output.
3.Fix some silk mistake
4.Change CD4504 VCC to 12V
5.Mirror EXP3 for Raspberry Pi.
6.Add R20 for F407 replace.
7.Add LED for the 3 fans

1.Add 5pin connector for BL-Touch
2.Change EXP1 & EXP2 mark
3.Add +/- mark

1.Add 48V stepstick support x3
2.Add TVS and Bleeding resistance to every stepstick socket
3.Change 12V/5A to SY8205
4.Change the Raspberry Pi 5V and system 5V to separate DC-DC circuits (3A per
channel)
5.Add separate 3.3V to stepsticks
6.Change PCB to 6 layers
7. Optimize some wiring.
8.Change the series diode of the driver circuit to a 15A fuse（1808）

1.Change 48V stepstick support to 2
2.Change 12V/5A to 12V/3A
3.Change the Raspberry Pi 5V (3A to 5A) and system 5V(5A to 3A )
4.Add RESET 1x2 Pin header

1.Add two thermistor sockets, a total of 6.
2.Change FAN0 to PA13，FAN1 to PA14。
3.Add pin definition silkscreen on the bottom.

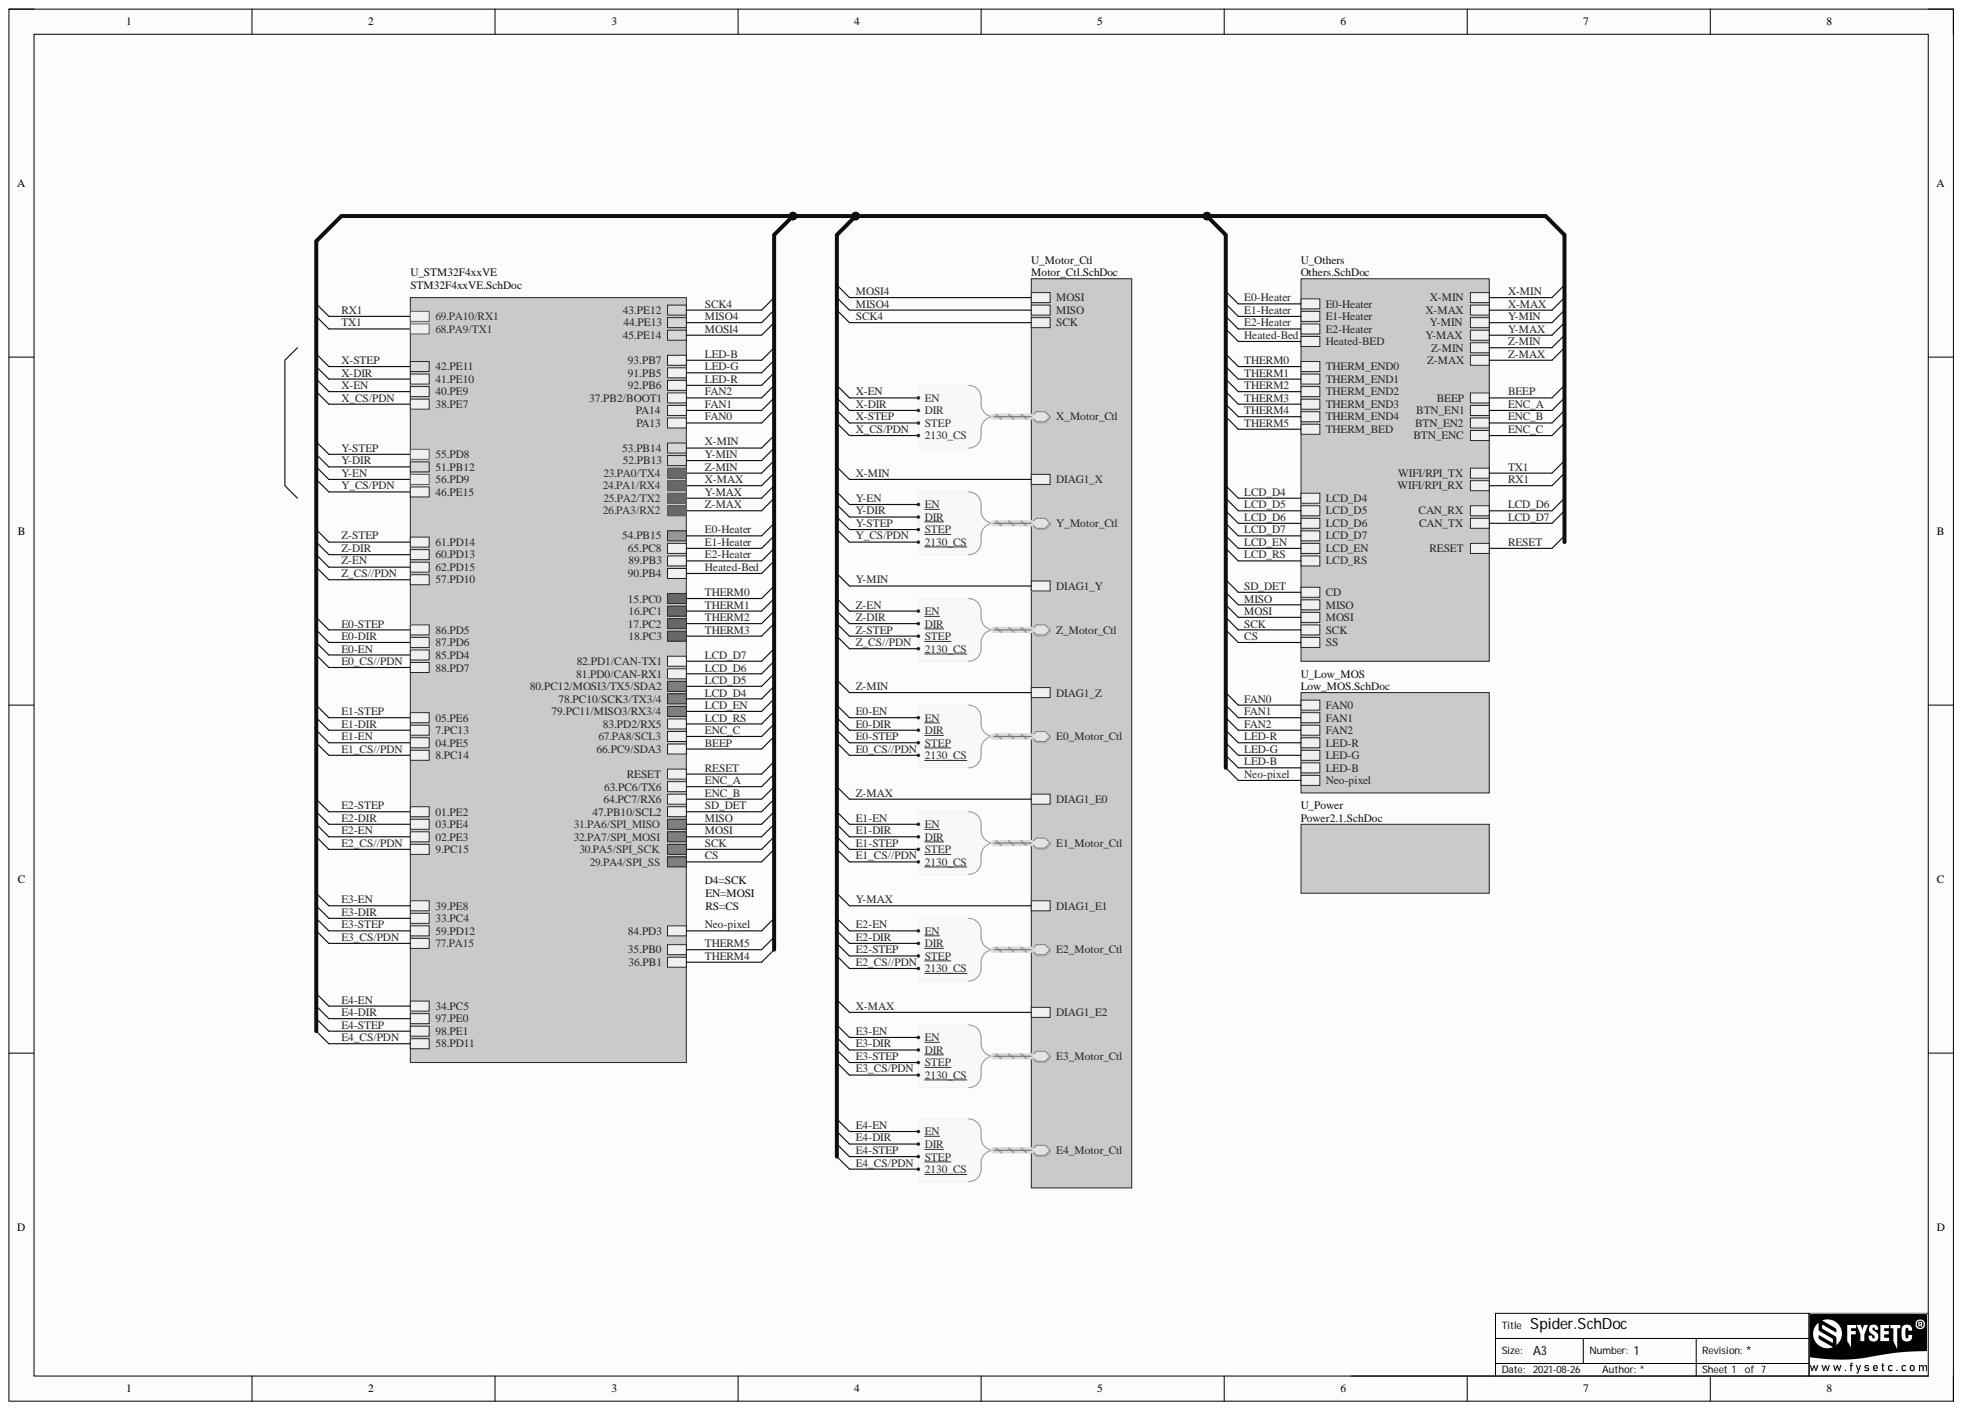
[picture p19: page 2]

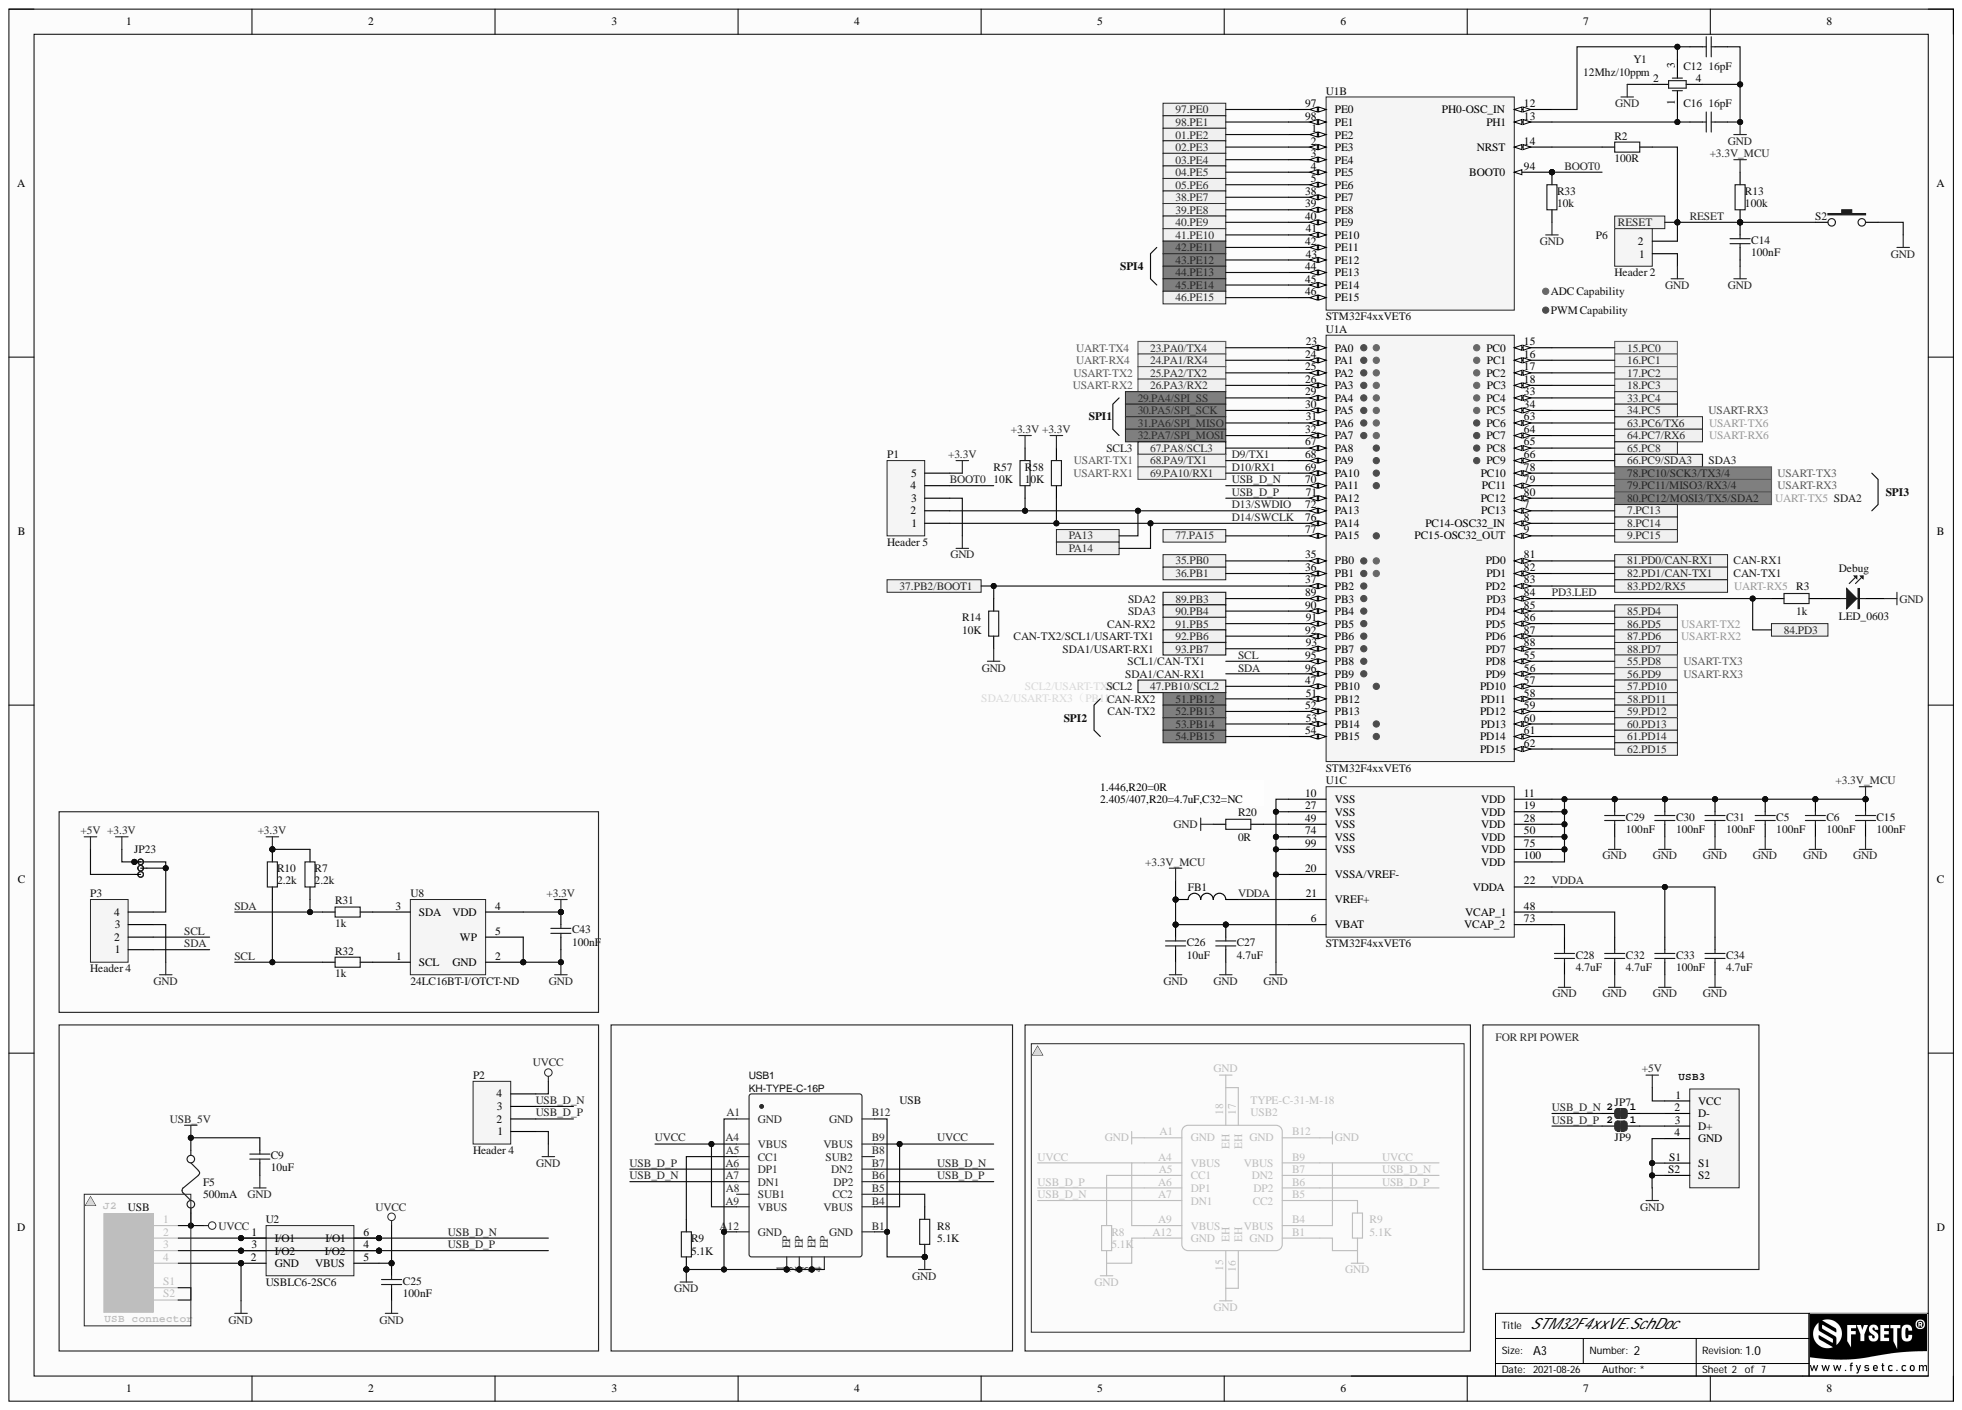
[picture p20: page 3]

02.PE3 03.PE4 | PE4 3 | 100R
04.PE5 | PE5 4
05.PE6 | PE7 38
38.PE7 | PE8 39

43.PE12 | PE12 43
44.PE13 | PE13 44
45.PE14 | PE15 46

24.PA1/RX4 | PA1 24 | 16.PC1
25.PA2/TX2 | PA3 26 | 17.PC2
26.PA3/RX2 | | 18.PC3
29.PA4/SPI_SS | PA4 29 | 33.PC4
30.PA5/SPI_SCK | PA5 30 | 34.PC5
31.PA6/SPI_MISO | PA7 32 | 63.PC6/TX6
32.PA7/SPI_MOSI | | 64.PC7/RX6
67.PA8/SCL3 | PA8 67 | 65.PC8

D14/SWCLK | PA14 76 | 7.PC13

35.PB0 | PB1 36 | | 81.PD0/CAN-RX1
36.PB1 | | | 82.PD1/CAN-TX1

89.PB3 | | PB4 90
90.PB4 | | | | 85.PD4
91.PB5 | | PB5 91 | | 86.PD5
92.PB6 | | PB6 92 | | 87.PD6 | 84.PD3
93.PB7 | SCL | PB8 95 | 88.PD7

47.PB10/SCL2 | PB12 51 | 57.PD10
51.PB12 | PB13 52 | 58.PD11
52.PB13 | | 59.PD12
53.PB14 | PB14 53 | 60.PD13
54.PB15 | | 61.PD14

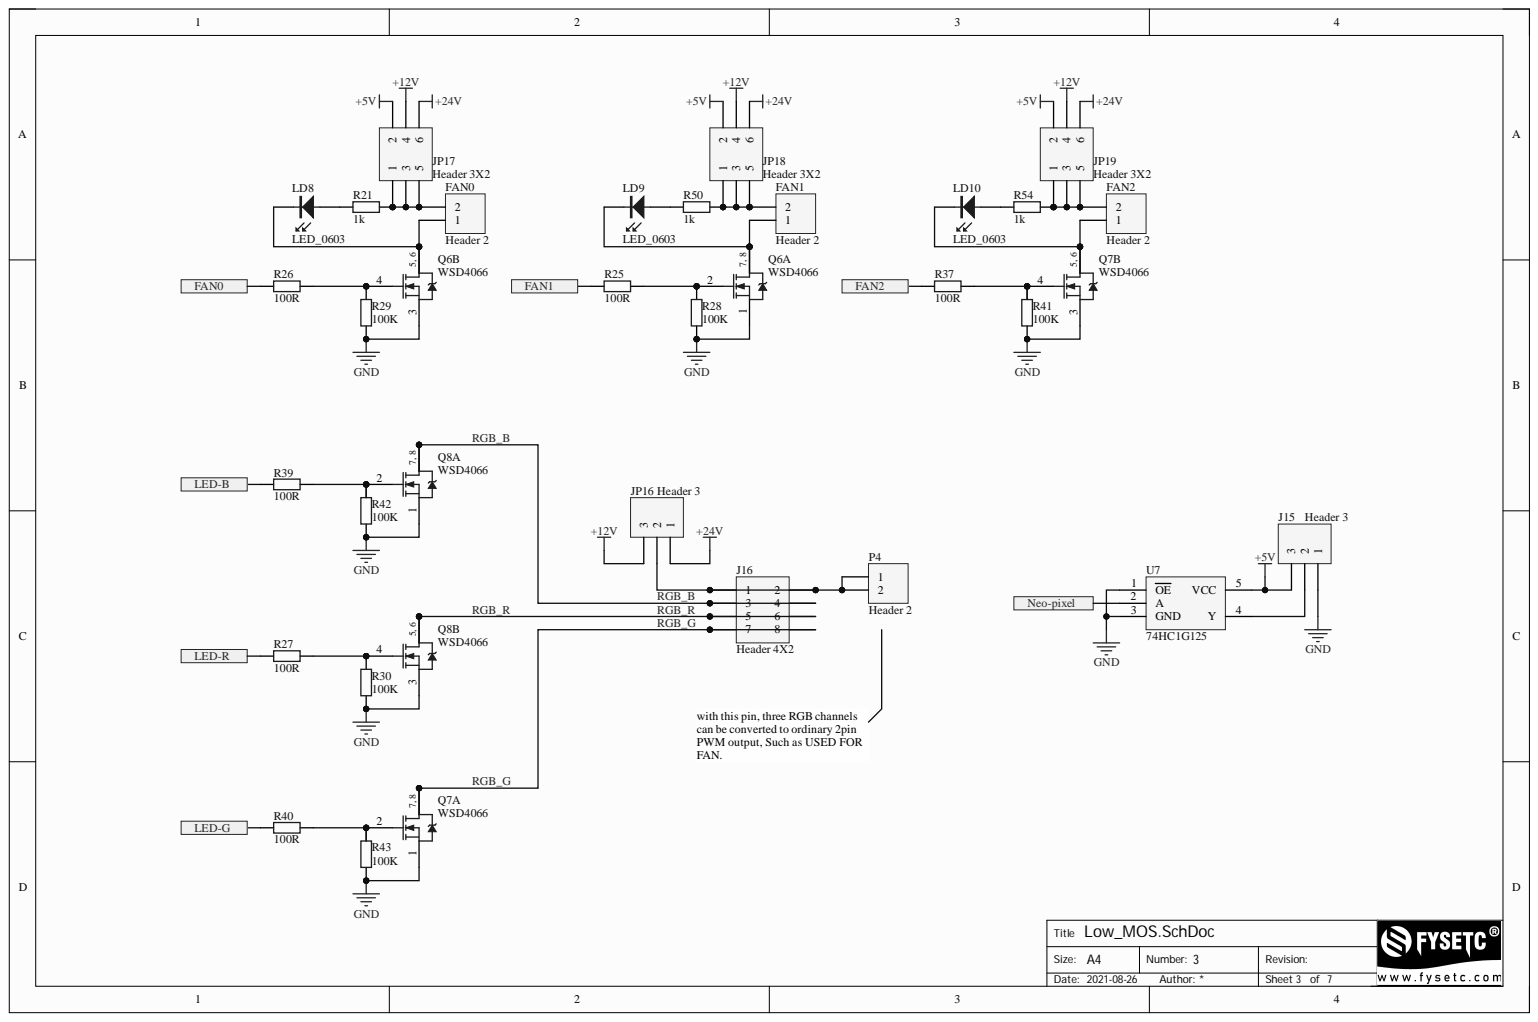
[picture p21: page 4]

RGB_G | 7 8

with this pin, three RGB channels
can be converted to ordinary 2pin
PWM output, Such as USED FOR
FAN.

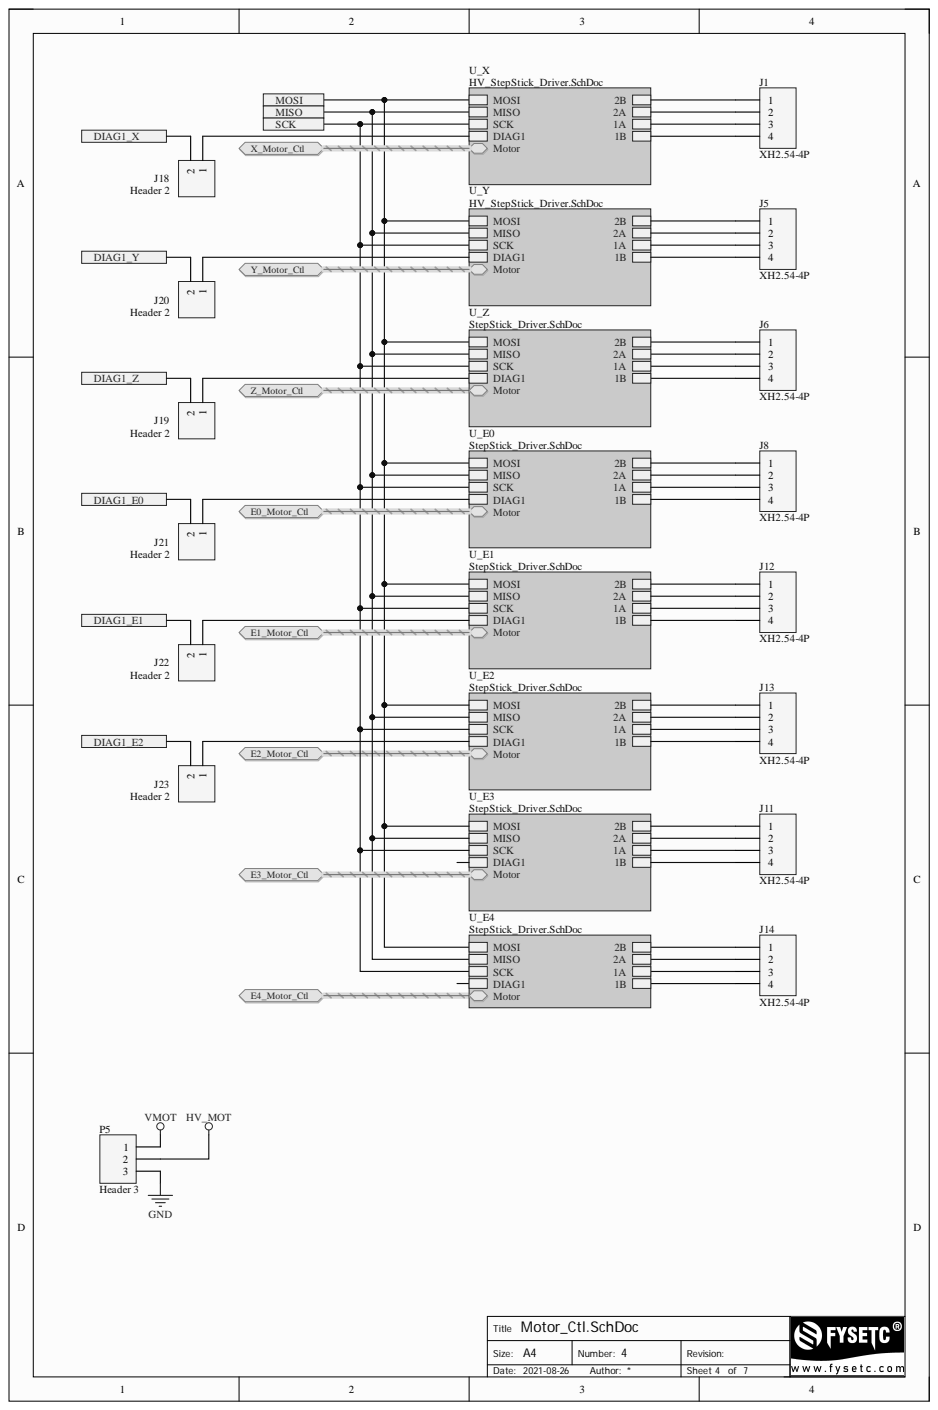
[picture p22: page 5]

M otor_Ctl .Sc hDo c T i t l e

S ize : A | N u m b er: | R e v i si o n :

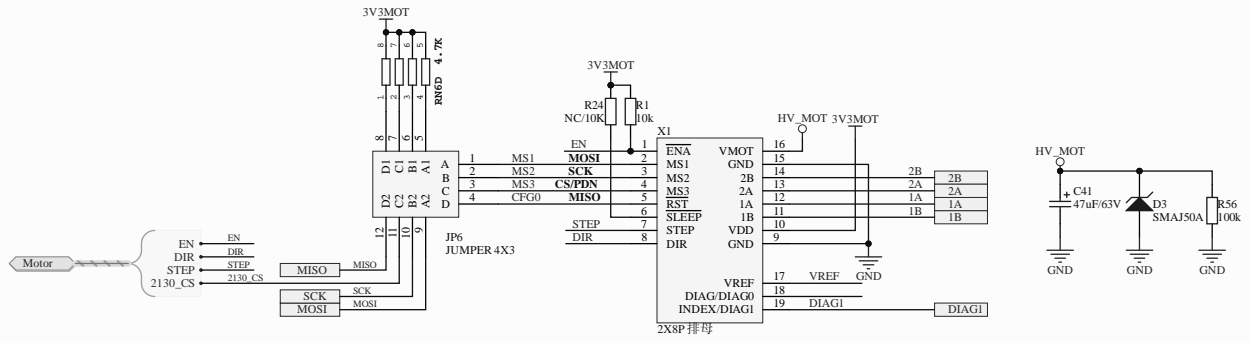
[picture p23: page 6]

2 MS2 SC K | 3 | 1 4
3 MS3 CS/ P D N | 4 | 1 3 | 2 A
4 CFG 0 ISO M | 5 | 1 2 | 1 A

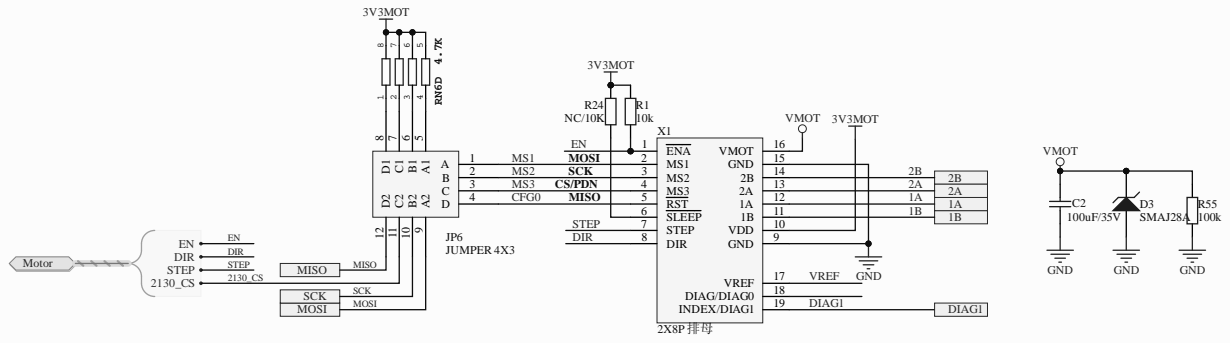
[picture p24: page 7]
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

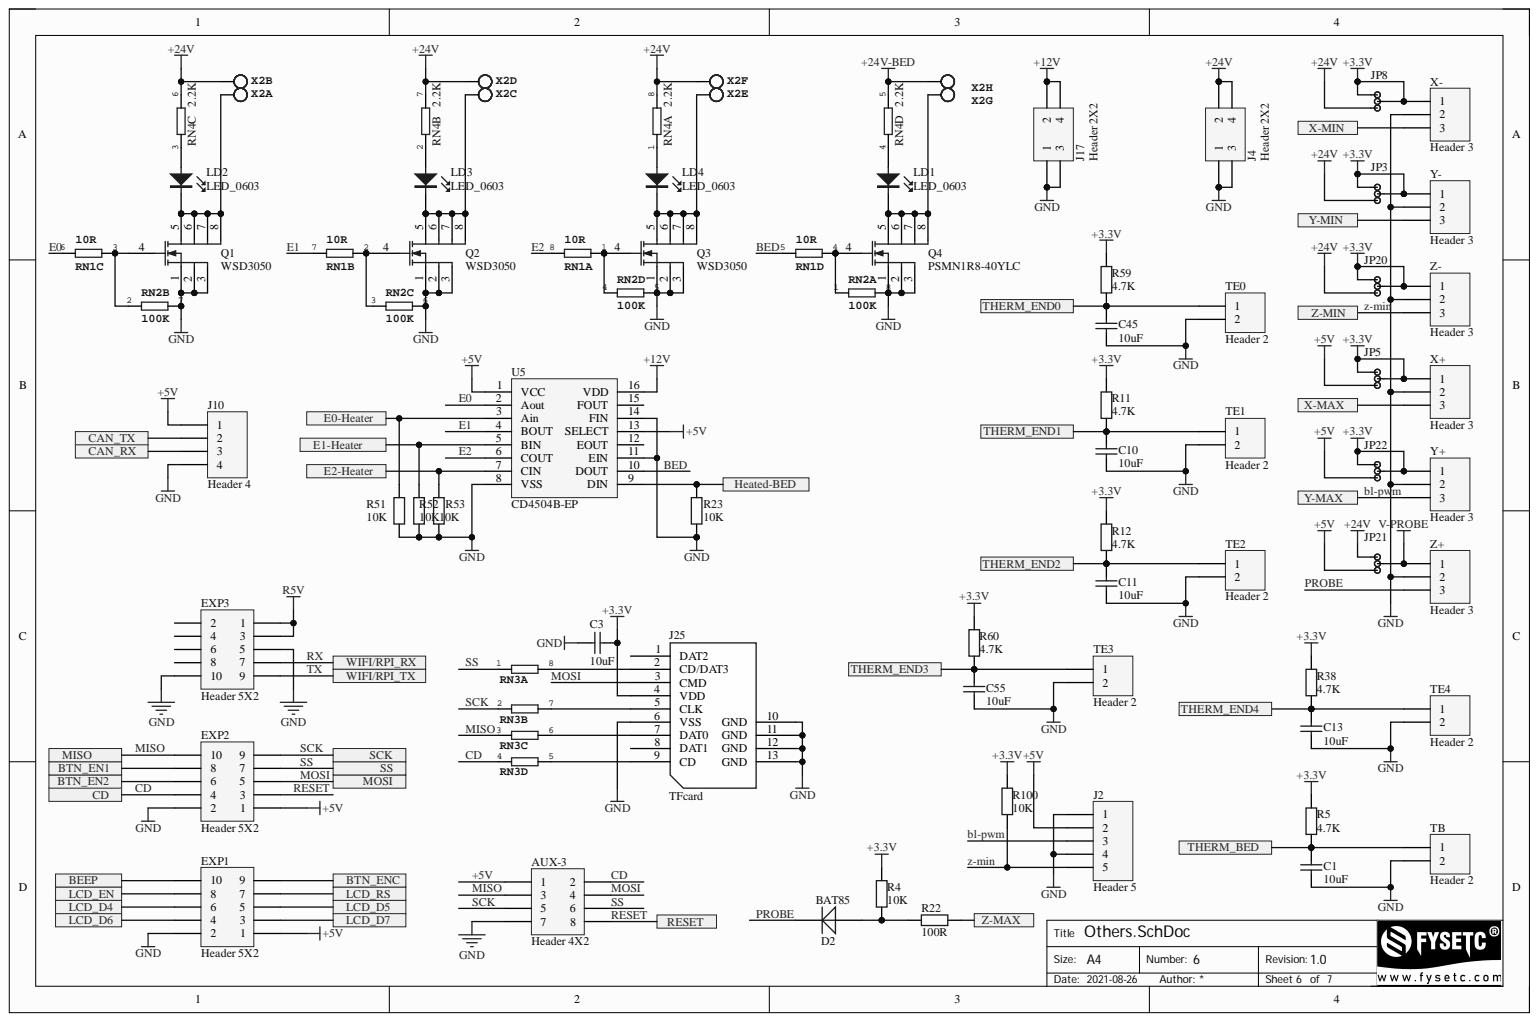
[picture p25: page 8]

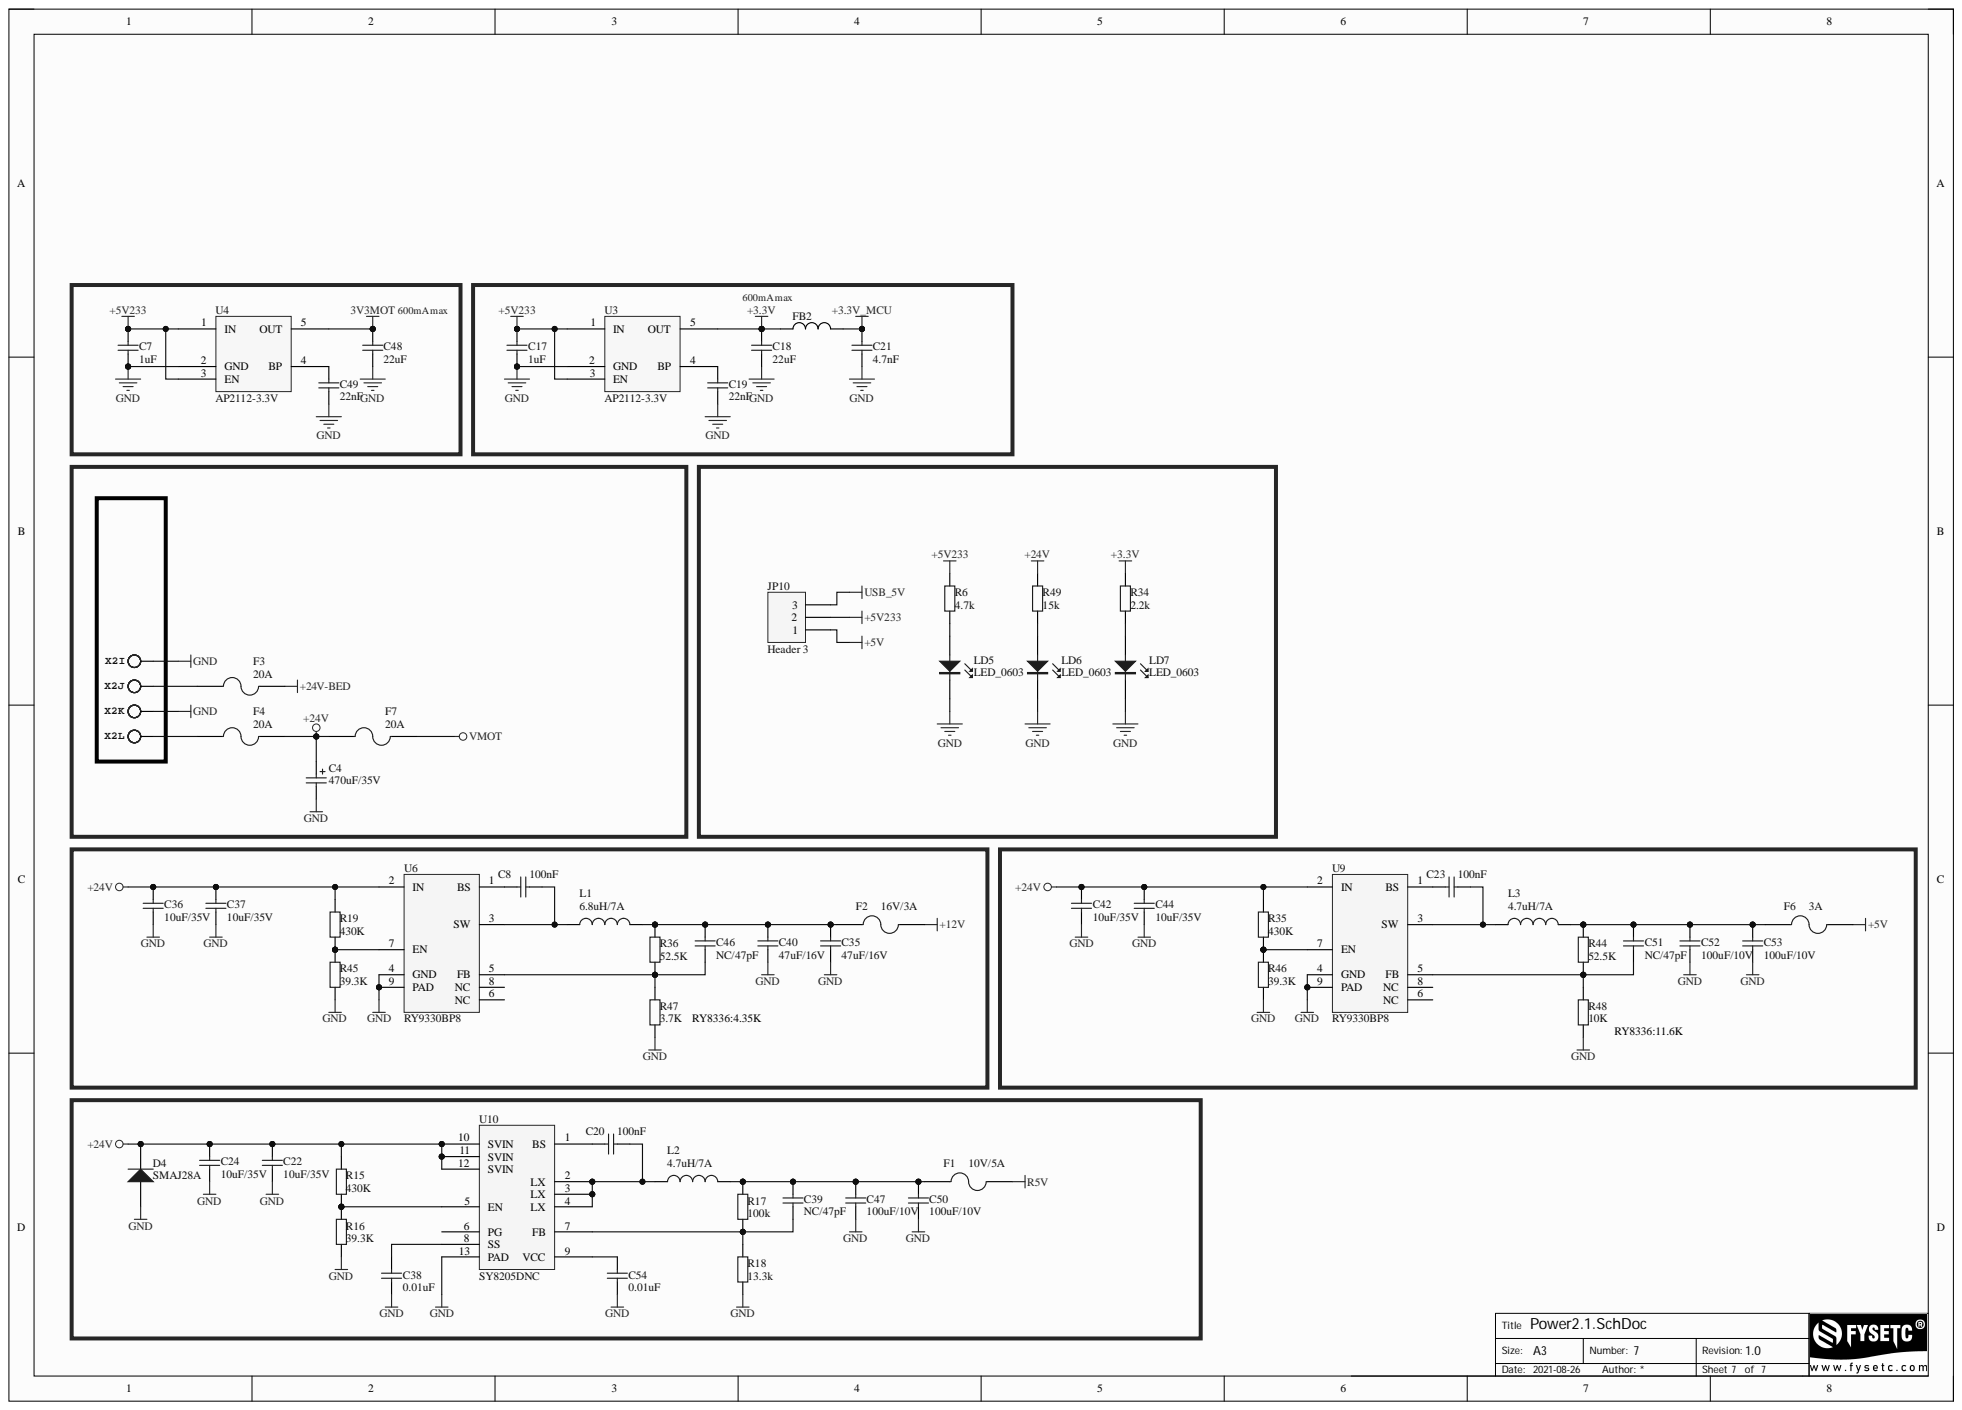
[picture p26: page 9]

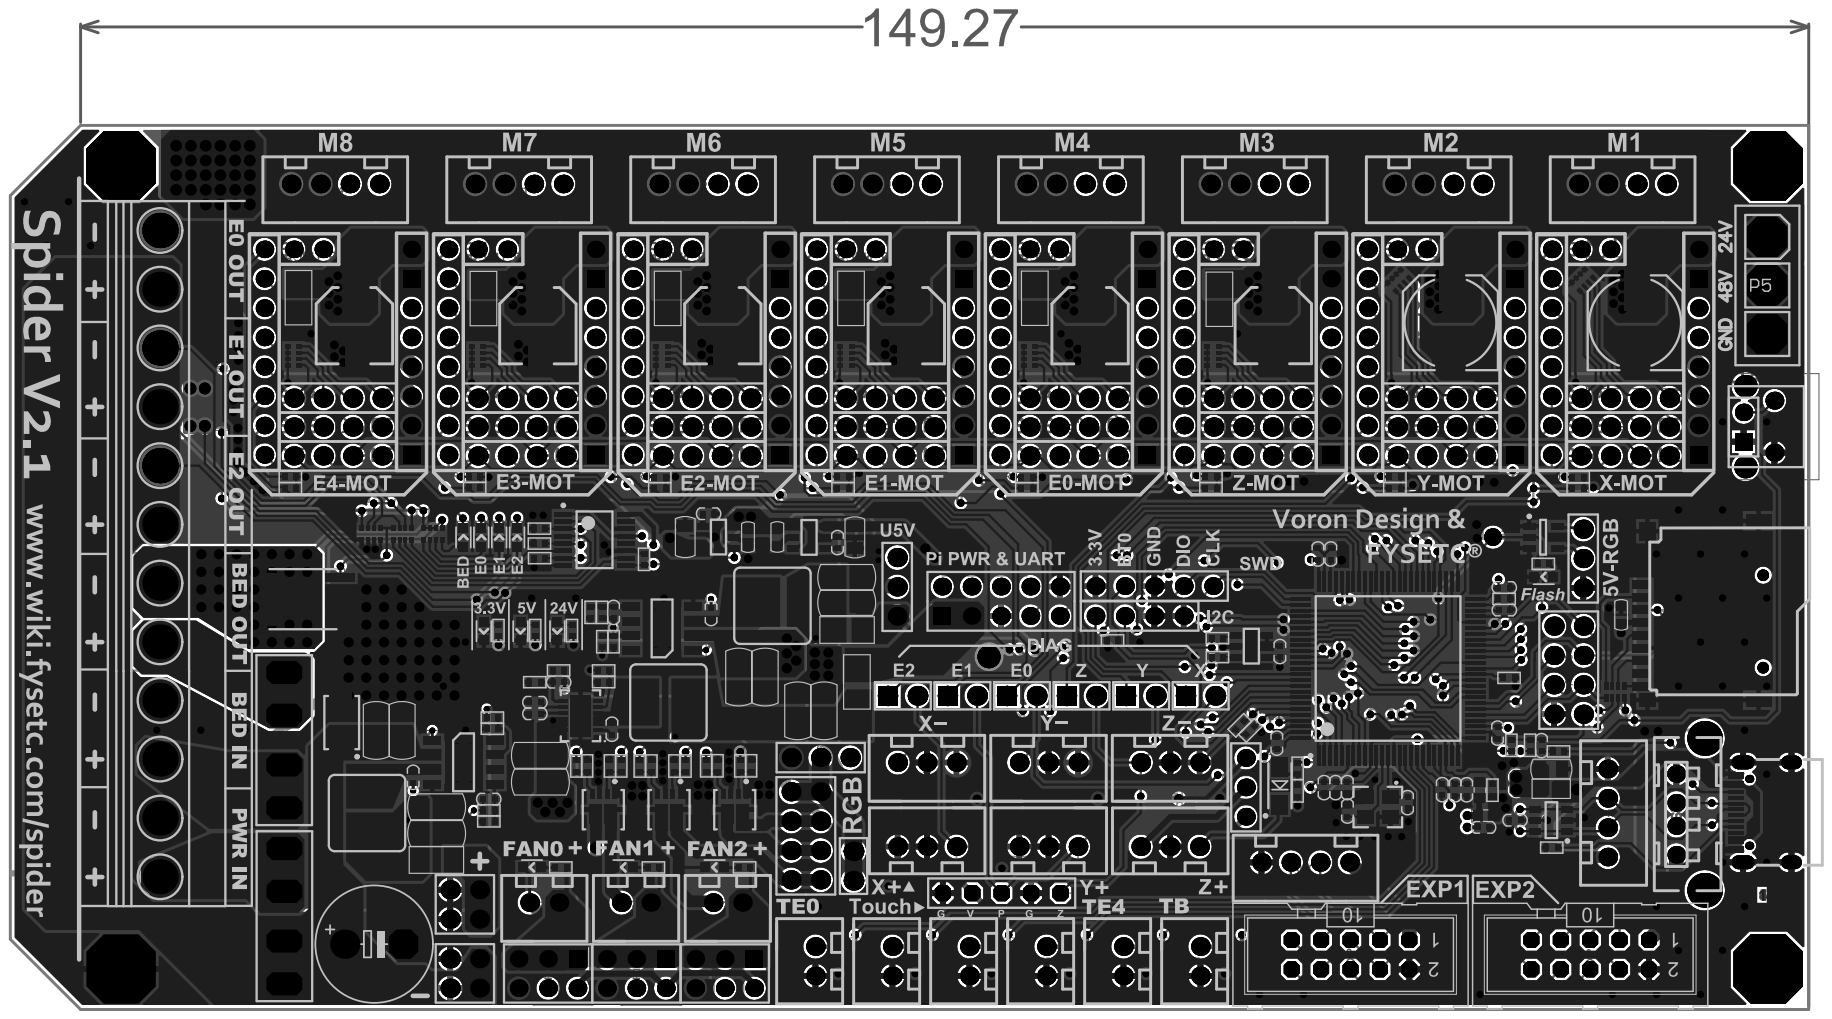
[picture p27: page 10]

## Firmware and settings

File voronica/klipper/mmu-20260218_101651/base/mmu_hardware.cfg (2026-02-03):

## Happy Hare MMU hardware config file with config for unknown MCU board
##
## Notes about setup of common external mcus can be found here:
##  https://github.com/moggieuk/Happy-Hare/blob/main/doc/mcu_notes.md
## 
## Note about "touch" endstops: Happy Hare provides extremely flexible homing options using both single steppers or synced steppers.
## The "touch" option leverages stallguard and thus requires the appropriate 'diag_pin' and stallguard parameters set on the TMC driver
## section.  If you have the diag_pin exposed, it is harmless to define this because they will only be used when explicitly needed
## and configured.
##
## Touch option for each stepper provides these benefits / possibilities (experimental):
##  - on extruder stepper allows for the automatic detection of the nozzle!
##  - on selector stepper allows for the automatic detection of filament stuck in the gate and subsequent recovery
##  - on gear stepper allows for the automatic detection of the extruder entrance
##
## These sound wonderful right?  They are, but there are caveats:
##  - The external EASY-BRD and ERB mcu's are terrible at detecting stallguard and often result in an "undervoltage error". It is generally
##    possible to get selector touch (TMC2209) tuned especially if you set 'stealthchop_threshold' to a value greater than homing speeds and
##    less than move speed. I.e. the stepper runs in stealthchop mode when homing. [klipper experts will know that it switches the chip mode
##    automatically to stealthchop and then back for Stallguard2 support, howver the automatic switching back to spreadcycle at the end homing
##    move seems to provoke the error condition and setting 'shealthchip_threshold' appropriately avoids this condition. More than you wanted
##    to know I'm sure!
##  - I have not had much luck with touch (stallguard) on the gear stepper with EASY-BRD and ERB mcu's and you really want the extra torque
##    of spreadcycle so adjusting 'stealthchop_threshold' is not really an option
##  - Enabling on the extruder stepper is viable but you will likley have to change jumpers on your main mcu to expose the DIAG pin for
##    whichever driver the extruder stepper is connected to.
##
## In summary, "touch" homing with your MMU is an advanced option that requires patience and careful tuning.  Luckily everything works with
## regular endstops and there are workaround options for certain homing points (like extruder entry) in the absence of any endstop.
## I'm really interested in creative setups that you come up with. Ping me on Discord (moggieuk#6538)
##
## See mmu.cfg for serial definition and pins aliaes
##
## HOMING CAPABLE EXTRUDER (VERY ADVANCED) ----------------------------------------------------------------------------------
## With Happy Hare installed even the extruder can be homed.  You will find the usual 'endstop' parameters can be added to your
## '[extruder]' section.  Useless you have some clever load cell attached to your nozzle it only really makes sense to configure 
## stallguard style "touch" homing. To do this add lines similar to this to your existing '[extruder]' definition whether
## you have it defined in printer.cfg.
##
##    [extruder]
##    endstop_pin: tmc2209_extruder:virtual_endstop
##
## Also be sure to add the appropriate stallguard config to the TMC section, e.g.
##
##    [tmc2209 extruder]
##    diag_pin: E_DIAG			# Set to MCU pin connected to TMC DIAG pin for extruder
##    driver_SGTHRS: 100		# 255 is most sensitive value, 0 is least sensitive
##
## Happy Hare will take care of the rest and add a 'mmu_ext_touch' endstop automatically
##

# MMU MACHINE / TYPE ---------------------------------------------------------------------------------------------------
# ███╗   ███╗███╗   ███╗██╗   ██╗    ███╗   ███╗ █████╗  ██████╗██╗  ██╗██╗███╗   ██╗███████╗
# ████╗ ████║████╗ ████║██║   ██║    ████╗ ████║██╔══██╗██╔════╝██║  ██║██║████╗  ██║██╔════╝
# ██╔████╔██║██╔████╔██║██║   ██║    ██╔████╔██║███████║██║     ███████║██║██╔██╗ ██║█████╗  
# ██║╚██╔╝██║██║╚██╔╝██║██║   ██║    ██║╚██╔╝██║██╔══██║██║     ██╔══██║██║██║╚██╗██║██╔══╝  
# ██║ ╚═╝ ██║██║ ╚═╝ ██║╚██████╔╝    ██║ ╚═╝ ██║██║  ██║╚██████╗██║  ██║██║██║ ╚████║███████╗
# ╚═╝     ╚═╝╚═╝     ╚═╝ ╚═════╝     ╚═╝     ╚═╝╚═╝  ╚═╝ ╚═════╝╚═╝  ╚═╝╚═╝╚═╝  ╚═══╝╚══════╝
[mmu_machine]
num_gates: 14				# Number of selectable gates on MMU
mmu_vendor: Tradrack			# MMU family
mmu_version: 1.0e			# MMU hardware version number (add mod suffix documented above)

# FILAMENT DRIVE GEAR STEPPER  ---------------------------------------------------------------------------------------------
# Note that 'toolhead' & 'mmu_gear' endstops will automatically be added if a toolhead sensor or gate sensor is defined
#
# The default values are tested with the ERCF BOM NEMA14 motor. Please adapt these values to the motor you are using
# Example : for NEMA17 motors, you'll usually use higher current
#
[tmc2209 stepper_mmu_gear]
uart_pin: mmu:MMU_TMC_UART
uart_address: 3
run_current: 1.27			# ERCF BOM NEMA14 motor
hold_current: 0.2			# Recommend to be small if not using "touch" or move (TMC stallguard)
interpolate: True
sense_resistor: 0.110			# Usually 0.11, 0.15 for BTT TMC2226
stealthchop_threshold: 0		# Spreadcycle has more torque and better at speed
#
# Uncomment two lines below if you have TMC and want the ability to use filament "touch" homing with gear stepper
#diag_pin: ^mmu:MMU_GEAR_DIAG		# Set to MCU pin connected to TMC DIAG pin for gear stepper
#driver_SGTHRS: 60			# 255 is most sensitive value, 0 is least sensitive

[stepper_mmu_gear]
step_pin: mmu:MMU_GEAR_STEP
dir_pin: !mmu:MMU_GEAR_DIR
enable_pin: !mmu:MMU_GEAR_ENABLE
#rotation_distance: 22.7316868		# Bondtech 5mm Drive Gears. Will be overriden by `mmu_gear_rotation_distance` in mmu_vars.cfg
rotation_distance: 22.67895 # default from tradrack docs, will be overridden by `mmu_gear_rotation_distance` in mmu_vars.cfg
gear_ratio: 50:17			# ERCF 80:20, Tradrack 50:17
microsteps: 16 				# Recommend 16
full_steps_per_rotation: 200		# 200 for 1.8 degree, 400 for 0.9 degree
#
# Uncomment the two lines below to enable filament "touch" homing option with gear motor
#extra_endstop_pins: tmc2209_stepper_mmu_gear:virtual_endstop
#extra_endstop_names: mmu_gear_touch


# SELECTOR STEPPER  --------------------------------------------------------------------------------------------------------
# Consult doc if you want to setup selector for "touch" homing instead or physical endstop
#
[tmc2209 stepper_mmu_selector]
uart_pin: mmu:MMU_TMC_UART
uart_address: 0
run_current: 0.63			# ERCF BOM NEMA17 motor
hold_current: 0.2			# Can be small if not using "touch" movement (TMC stallguard)
interpolate: True
sense_resistor: 0.110
stealthchop_threshold: 100		# Stallguard "touch" movement (slower speeds) best done with stealthchop
#
# Uncomment two lines below if you have TMC and want to use selector "touch" movement
#diag_pin: ^mmu:MMU_SEL_DIAG 		# Set to MCU pin connected to TMC DIAG pin for selector stepper
#driver_SGTHRS: 75			# 255 is most sensitive value, 0 is least sensitive

[stepper_mmu_selector]
step_pin: mmu:MMU_SEL_STEP
dir_pin: !mmu:MMU_SEL_DIR
enable_pin: !mmu:MMU_SEL_ENABLE
rotation_distance: 40
microsteps: 16 				# Don't need high fidelity
full_steps_per_rotation: 200		# 200 for 1.8 degree, 400 for 0.9 degree
endstop_pin: ^mmu:MMU_SEL_ENDSTOP	# Selector microswitch
endstop_name: mmu_sel_home
#
# Uncomment two lines below to give option of selector "touch" movement
#extra_endstop_pins: tmc2209_stepper_mmu_selector:virtual_endstop
#extra_endstop_names: mmu_sel_touch


# SELECTOR SERVO -----------------------------------------------------------------------------------------------------------
# Basic servo PWM setup. If these values are changed then the angles defined for different positions will also change
#
[mmu_servo selector_servo]
pin: mmu:MMU_SERVO
maximum_servo_angle: 131
minimum_pulse_width: 0.00070
maximum_pulse_width: 0.00220


# OPTIONAL GANTRY SERVO FOR FILAMETRIX FILAMENT CUTTER --------------------------------------------------------------------
# Basic servo PWM setup. If these values are changed then the angles defined for different positions will also change
#
# Uncomment only if you have gantry servo
#
#[mmu_servo mmu_gantry_servo]
#pin: 
#maximum_servo_angle:180
#minimum_pulse_width: 0.00075
#maximum_pulse_width: 0.00225
#initial_angle: 180
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

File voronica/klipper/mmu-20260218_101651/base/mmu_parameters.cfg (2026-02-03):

########################################################################################################################
# Happy Hare MMU Software
#
# EDIT THIS FILE BASED ON YOUR SETUP
#
# Copyright (C) 2022  moggieuk#6538 (discord) moggieuk@hotmail.com
# This file may be distributed under the terms of the GNU GPLv3 license.
#
# Goal: Main configuration parameters for the klipper module
#
# (\_/)
# ( *,*)
# (")_(") Happy Hare Ready
#
# Notes:
#   Macro configuration is specified separately in 'mmu_macro_vars.cfg'.
#   Full details in https://github.com/moggieuk/Happy-Hare/tree/main/doc/configuration.md
#
[mmu]
happy_hare_version: 3.01			# Don't mess, used for upgrade detection

# MMU Hardware Limits --------------------------------------------------------------------------------------------------
# ██╗     ██╗███╗   ███╗██╗████████╗███████╗
# ██║     ██║████╗ ████║██║╚══██╔══╝██╔════╝
# ██║     ██║██╔████╔██║██║   ██║   ███████╗
# ██║     ██║██║╚██╔╝██║██║   ██║   ╚════██║
# ███████╗██║██║ ╚═╝ ██║██║   ██║   ███████║
# ╚══════╝╚═╝╚═╝     ╚═╝╚═╝   ╚═╝   ╚══════╝
#
# Define the physical limits of your MMU. These settings will be respected regardless of individual speed settings.
#
gear_max_velocity: 300			# Never to be exceeded gear velocity regardless of specific parameters
gear_max_accel: 1500			# Never to be exceeded gear acceleration regardless of specific parameters
selector_max_velocity: 250		# Never to be exceeded selector velocity regardless of specific parameters
selector_max_accel: 1200		# Never to be exceeded selector acceleration regardless of specific parameters


# Servo configuration  -------------------------------------------------------------------------------------------------
# ███████╗███████╗██████╗ ██╗   ██╗ ██████╗ 
# ██╔════╝██╔════╝██╔══██╗██║   ██║██╔═══██╗
# ███████╗█████╗  ██████╔╝██║   ██║██║   ██║
# ╚════██║██╔══╝  ██╔══██╗╚██╗ ██╔╝██║   ██║
# ███████║███████╗██║  ██║ ╚████╔╝ ╚██████╔╝
# ╚══════╝╚══════╝╚═╝  ╚═╝  ╚═══╝   ╚═════╝ 
#
# Angle of the servo in three named positions
#   up   = tool is selected and filament is allowed to freely move through gate
#   down = to grip filament
#   move = ready the servo for selector move (optional - defaults to up)
# V2.4.0 on: These positions are only for initial config they are replaced with calibrated servo positions in `mmu_vars.cfg`
#
# Note that leaving the servo active when down can stress the electronics and is not recommended with EASY-BRD or ERB board
# unless the 5v power supply has been improved and it is not necessary with standard ERCF builds
# Make sure your hardware is suitable for the job!
#
servo_up_angle: 145			# ERCF: MG90S: 30  ; SAVOX SH0255MG: 140 ; Tradrack: 145
servo_down_angle: 1			# ERCF: MG90S: 140 ; SAVOX SH0255MG: 30  ; Tradrack: 1
servo_move_angle: 145			# Optional angle used when selector is moved (defaults to up position)
servo_duration: 0.2			# Duration of PWM burst sent to servo (default non-active mode, automatically turns off)
servo_dwell: 0.5			# Minimum time given to servo to complete movement prior to next move
servo_always_active: 0 			# CAUTION: 1=Force servo to always stay active, 0=Release after movement
servo_active_down: 0			# CAUTION: 1=Force servo to stay active when down only, 0=Release after movement
servo_buzz_gear_on_down: 0		# Whether to "buzz" the gear stepper on down to aid engagement


# Logging --------------------------------------------------------------------------------------------------------------
# ██╗      ██████╗  ██████╗  ██████╗ ██╗███╗   ██╗ ██████╗ 
# ██║     ██╔═══██╗██╔════╝ ██╔════╝ ██║████╗  ██║██╔════╝ 
# ██║     ██║   ██║██║  ███╗██║  ███╗██║██╔██╗ ██║██║  ███╗
# ██║     ██║   ██║██║   ██║██║   ██║██║██║╚██╗██║██║   ██║
# ███████╗╚██████╔╝╚██████╔╝╚██████╔╝██║██║ ╚████║╚██████╔╝
# ╚══════╝ ╚═════╝  ╚═════╝  ╚═════╝ ╚═╝╚═╝  ╚═══╝ ╚═════╝ 
#
# log_level & logfile_level can be set to one of (0 = essential, 1 = info, 2 = debug, 3 = trace, 4 = stepper moves)
# Generally you can keep console logging to a minimal whilst still sending debug output to the mmu.log file
# Increasing the console log level is only really useful during initial setup to save having to constantly open the log file
# Note: that it is not recommended to keep logging at level greater that 2 (debug) if not debugging an issue because
# of the additional overhead
#
log_level: 1
log_file_level: 2			# Can also be set to -1 to disable log file completely
log_statistics: 1 			# 1 to log statistics on every toolchange (default), 0 to disable (but still recorded)
log_visual: 1				# 1 log visual representation of filament, 0 = disable
log_startup_status: 1			# Whether to log tool to gate status on startup, 1 = summary (default), 0 = disable
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

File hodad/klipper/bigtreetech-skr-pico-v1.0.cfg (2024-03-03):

# This file contains common pin mappings for the BIGTREETECH SKR Pico V1.0
# To use this config, the firmware should be compiled for the RP2040 with
# USB communication.

# The "make flash" command does not work on the SKR Pico V1.0. Instead,
# after running "make", copy the generated "out/klipper.uf2" file
# to the mass storage device in RP2040 boot mode

## Voron Design VORON 0.2 SKR Pico V1.0 config

## *** THINGS TO CHANGE/CHECK: ***
## MCU path                                                                     [mcu] section
## Z and Extruder motor currents                                                [tmc2209 stepper_*] sections. Uncomment the stepper motor you have
## Full steps per rotation for Extruder                                         [extruder] section
## Thermistor types                                                             [extruder] and [heater_bed] sections - See https://www.klipper3d.org/Config_Reference.html#common-thermistors for common thermistor types
## Motor currents                                                               [extruder] [stepper] and [_HOME_X/Y] macro sections
## PID tune                                                                     [extruder] and [heater_bed] sections
## Fine tune E steps                                                            [extruder] section
## For more info                                                                check https://docs.vorondesign.com/build/startup/#v0

[mcu]
#####################################################################
# Obtain definition by "ls -l /dev/serial/by-id/"
#####################################################################
##serial: /dev/serial/by-id/usb-Klipper_rp2040_4550357128923CB8-if00
## serial: /dev/ttyAMA0 											# for UART connection on RPi
## serial: /dev/ttyS0 # for UART on BTT Pi
serial: /dev/serial0
restart_method: command


[temperature_sensor mcu_temp]
sensor_type: temperature_mcu
min_temp: 0
max_temp: 100

[printer]
kinematics: corexy
max_velocity: 550
max_accel: 18000
max_z_velocity: 15
max_z_accel: 500
square_corner_velocity: 6.0

#####################################################################
#      X/Y Stepper Settings
#####################################################################

[stepper_x]
step_pin: gpio11
## Refer to https://docs.vorondesign.com/build/startup/#v0
dir_pin: gpio10                                                     # Check motor direction in link above. If inverted, add a ! before gpio10
enable_pin: !gpio12
rotation_distance: 40
microsteps: 32
full_steps_per_rotation: 200                                        # Set to 400 for 0.9° degree stepper motor, 200 is for 1.8° stepper motors
endstop_pin: tmc2209_stepper_x:virtual_endstop
position_endstop: 120
position_max: 120
homing_speed: 20                                                    # for sensorless homing it is recommended not to go above 40mm/s   
homing_retract_dist: 0
homing_positive_dir: true

[tmc2209 stepper_x]
uart_pin: gpio9
tx_pin: gpio8
uart_address: 0
interpolate: False
run_current: 0.69 # max 1.0605            
# you need to calculate the run_current value using the equation (rated_motor_current * 0.707 = Maximum_run_current) start with a value that is about 60%-70% of your maximum value.
sense_resistor: 0.110
stealthchop_threshold: 0                                            # Set to 999999 to turn stealthchop on, and 0 to use spreadcycle
diag_pin: ^gpio4    												# YOU NEED TO JUMP THIS DIAG PIN ON YOUR BOARD FOR SENSORLESS HOMING TO WORK 
driver_SGTHRS: 55

[stepper_y]
step_pin: gpio6
## Refer to https://docs.vorondesign.com/build/startup/#v0
dir_pin: gpio5                                                      # Check motor direction in link above. If inverted, add a ! before gpio5
enable_pin: !gpio7
rotation_distance: 40
microsteps: 32
full_steps_per_rotation: 200                                        # Set to 400 for 0.9° degree stepper motor, 200 is for 1.8° stepper motors
endstop_pin: tmc2209_stepper_y:virtual_endstop
position_endstop: 120
position_max: 120
homing_speed: 20                                                    # for sensorless homing it is recommended not to go above 40mm/s   
homing_retract_dist: 0
homing_positive_dir: true

[tmc2209 stepper_y]
uart_pin: gpio9
tx_pin: gpio8
uart_address: 2
interpolate: False
run_current: 0.69 # max 1.0605            
# you need to calculate the run_current value using the equation (rated_motor_current * 0.707 = Maximum_run_current) start with a value that is about 60%-70% of your maximum value.
sense_resistor: 0.110
stealthchop_threshold: 0                                            # Set to 999999 to turn stealthchop on, and 0 to use spreadcycle
diag_pin: ^gpio3    												# YOU NEED TO JUMP THIS DIAG PIN ON YOUR BOARD FOR SENSORLESS HOMING TO WORK 
driver_SGTHRS: 55

#####################################################################
#   Z Stepper Settings
#####################################################################

[stepper_z]
step_pin: gpio19
dir_pin: !gpio28                                                    # Remove the ! before gpio28 if motor direction is inverted.
enable_pin: !gpio2
rotation_distance: 8                                                # For T8x8 integrated lead screw
microsteps: 32
endstop_pin: ^gpio25
#position_endstop: 120
position_max: 120
position_min: -1.5
homing_speed: 20
second_homing_speed: 3.0
homing_retract_dist: 3.0


[tmc2209 stepper_z]
uart_pin: gpio9
tx_pin: gpio8
uart_address: 1
interpolate: False
## For OMC (StepperOnline) 17LS13-0404E-200G 0.4A 
#run_current: 0.2
## For LDO-42STH25-1004CL200E 1.0A
#run_current: 0.37
run_current: 0.3 # max 0.45955
sense_resistor: 0.110
stealthchop_threshold: 0                                            # Set to 999999 to turn stealthchop on, and 0 to use spreadcycle

# #####################################################################
# #   Extruder
# #####################################################################

# [extruder]
# step_pin: gpio14
# dir_pin: gpio13                                                     # Add ! if moving opposite direction
# enable_pin: !gpio15
# #full_steps_per_rotation: 200                                       # Set to 200 for LDO 1.8° stepper motor, and set to 400 for OMC(StepperOnline) 0.9° stepper motor
# rotation_distance: 22.23                                            # See calibrating rotation_distance on extruders doc
# gear_ratio: 50:10                                                   # For Mini Afterburner
# microsteps: 32
# #nozzle_diameter: 0.400
# nozzle_diameter: 0.600
# filament_diameter: 1.750
# heater_pin: gpio23
# ## Check what thermistor type you have. See https://www.klipper3d.org/Config_Reference.html#common-thermistors for common thermistor types.
# ## Use "Generic 3950" for NTC 100k 3950 thermistors
# sensor_type: ATC Semitec 104NT-4-R025H42G
# sensor_pin: gpio27
# #control: pid                                                        # Do PID calibration after initial checks
# #pid_Kp: 28.182
# #pid_Ki: 1.978
# #pid_Kd: 100.397
# min_temp: 0
# max_temp: 270
# min_extrude_temp: 170
# max_extrude_only_distance: 150
# max_extrude_cross_section: 1.3 # was 0.8
# pressure_advance: 0.0                                               # See tuning pressure advance doc
# pressure_advance_smooth_time: 0.040

# [tmc2209 extruder]
# uart_pin: gpio9
# tx_pin: gpio8
# uart_address: 3
# interpolate: False
# ## For OMC (StepperOnline) 14HR07-1004VRN 1A 0.9°
# #run_current: 0.5 # for OMC 14HR07-1004VRN rated at 1A
# ## For LDO LDO 36STH17-1004AHG 1A 1.8° 
# #run_current: 0.3 # for LDO 36STH17-1004AHG
# ## For LDO LDO 36STH20-1004AHG 1A 1.8° 
# #run_current: 0.6 # for LDO 36STH20-1004AHG
# run_current: 0.46 # max 0.707
# sense_resistor: 0.110
# stealthchop_threshold: 0                                            # Set to 0 for spreadcycle, avoid using stealthchop on extruder

# #####################################################################
# #   Bed Heater
# #####################################################################

[heater_bed]
heater_pin: gpio21
## Check what thermistor type you have. See https://www.klipper3d.org/Config_Reference.html#common-thermistors for common thermistor types.
## Use "Generic 3950" for Keenovo heaters
#sensor_type: Generic 3950
sensor_type: ATC Semitec 104GT-2
sensor_pin: gpio26
smooth_time: 3.0
#max_power: 0.6                                                     # Only needed for 100w pads with 150w PSU
max_power: 1.0
min_temp: 0
max_temp: 120
#control: pid                                                        # Do PID calibration after initial checks
#pid_kp: 68.453
#pid_ki: 2.749
#pid_kd: 426.122

#####################################################################
# Fan Control
#####################################################################
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

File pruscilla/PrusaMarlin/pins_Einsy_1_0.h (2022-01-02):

/*****************************************************************
* EINSY Rambo 1.0a Pin Assignments
******************************************************************/

#define ELECTRONICS "EINSy_10a"

#define KNOWN_BOARD
#ifndef __AVR_ATmega2560__
  #error Oops!  Make sure you have 'Arduino Mega 2560 or Rambo' selected from the 'Tools -> Boards' menu.
#endif

#define TMC2130
#define UVLO_SUPPORT

#define AMBIENT_THERMISTOR
#define PINDA_THERMISTOR

#define XFLASH                 // external 256kB flash
#define BOOTAPP                  // bootloader support

#define XFLASH_PIN_CS          32

#define X_TMC2130_CS           41
#define X_TMC2130_DIAG         64 // !!! changed from 40 (EINY03)
#define X_STEP_PIN             37
#define X_DIR_PIN              49
#define X_MIN_PIN            12
//#define X_MAX_PIN            30
//#define X_MIN_PIN              X_TMC2130_DIAG
#define X_MAX_PIN              X_TMC2130_DIAG
#define X_ENABLE_PIN           29
#define X_MS1_PIN           -1
#define X_MS2_PIN           -1

#define Y_TMC2130_CS        39
#define Y_TMC2130_DIAG      69
#define Y_STEP_PIN          36
#define Y_DIR_PIN           48
#define Y_MIN_PIN           11
//#define Y_MAX_PIN           24
//#define Y_MIN_PIN           Y_TMC2130_DIAG
#define Y_MAX_PIN           Y_TMC2130_DIAG
#define Y_ENABLE_PIN        28
#define Y_MS1_PIN           -1
#define Y_MS2_PIN           -1

#define Z_TMC2130_CS        67
#define Z_TMC2130_DIAG      68
#define Z_STEP_PIN          35
#define Z_DIR_PIN           47
#define Z_MIN_PIN           10
#define Z_MAX_PIN           23
//#define Z_MAX_PIN           Z_TMC2130_DIAG
#define Z_ENABLE_PIN        27
#define Z_MS1_PIN           -1
#define Z_MS2_PIN           -1

#define HEATER_BED_PIN       4 //PG5
#define TEMP_BED_PIN         2 //A2

#define HEATER_0_PIN         3 //PE5
//#define TEMP_0_PIN           0 //A0
#define TEMP_0_PIN           1 //A1 as A0 is fried

#define HEATER_1_PIN        -1
//#define TEMP_1_PIN           1 //A1
#define TEMP_1_PIN           0 //A0 (this pin is unused)

#define HEATER_2_PIN        -1
#define TEMP_2_PIN          -1

#define TEMP_AMBIENT_PIN     6 //A6

#define TEMP_PINDA_PIN       3 //A3

#define VOLT_PWR_PIN         4 //A4
#define VOLT_BED_PIN         9 //A9
#define VOLT_IR_PIN          8 //A8


#define E0_TMC2130_CS       66
#define E0_TMC2130_DIAG     65
#define E0_STEP_PIN         34
#define E0_DIR_PIN          43
#define E0_ENABLE_PIN       26
#define E0_MS1_PIN          -1
#define E0_MS2_PIN          -1

#define SDPOWER             -1
#define SDSS                77
#define LED_PIN             13
#define FAN_PIN              6
#define FAN_1_PIN           -1
#define PS_ON_PIN           -1
#define KILL_PIN            -1  // 80 with Smart Controller LCD
#define SUICIDE_PIN         -1  // PIN that has to be turned on right after start, to keep power flowing.


//#define KILL_PIN            32

#define LCD_BL_PIN          5   //backlight control pin
#define BEEPER              84  // Beeper on AUX-4
#define LCD_PINS_RS         82
#define LCD_PINS_ENABLE     61 // !!! changed from 18 (EINY03)
#define LCD_PINS_D4	        59 // !!! changed from 19 (EINY03)
#define LCD_PINS_D5         70
#define LCD_PINS_D6         85
#define LCD_PINS_D7         71

//buttons are directly attached using AUX-2
#define BTN_EN1                72
#define BTN_EN2                14
#define BTN_ENC                 9  // the click

#define SDCARDDETECT           15

#define TACH_0                 79 // !!! changed from 81 (EINY03)
#define TACH_1                 80 

#define IR_SENSOR_PIN 62 //idler sensor @PK0 (digital pin 62/A8)

#define MMU_RST_PIN 76

// Support for an 8 bit logic analyzer, for example the Saleae.
// Channels 0-2 are fast, they could generate 2.667Mhz waveform with a software loop.
#define LOGIC_ANALYZER_CH0		X_MIN_PIN		// PB6
#define LOGIC_ANALYZER_CH1		Y_MIN_PIN		// PB5
#define LOGIC_ANALYZER_CH2		53				// PB0 (PROC_nCS)
// Channels 3-7 are slow, they could generate
// 0.889Mhz waveform with a software loop and interrupt locking,
// 1.333MHz waveform without interrupt locking.
#define LOGIC_ANALYZER_CH3 		73				// PJ3
// PK0 has no Arduino digital pin assigned, so we set it directly.
#define WRITE_LOGIC_ANALYZER_CH4(value) if (value) PORTK |= (1 << 0); else PORTK &= ~(1 << 0) // PK0
#define LOGIC_ANALYZER_CH5		16				// PH0 (RXD2)
#define LOGIC_ANALYZER_CH6		17				// PH1 (TXD2)
#define LOGIC_ANALYZER_CH7 		76				// PJ5
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

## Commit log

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2022-09-09 fix esteps, update arms
    [printer.cfg]
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2022-09-09 Toggle lights using gcode button
    Found the duplicate_pin_override feature which lets me use the same
    pin for the z axis probe and for a button. This lets me toggle a
    red light on and off based on the bed probe triggering.
    [printer.cfg]
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2022-10-09 Refactor config
    Make it look similar to the RatOS config
    [base.cfg, btt-skr-pico.cfg, btt-smartie.cfg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]
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2022-11-02 Tune stall guard threshold
    [sensorless-homing.cfg]
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2022-11-02 Remove PID so that printer.cfg can handle it
    [v6-clone.cfg]
2022-11-02 Move purge line inward, reset extruder
    [start-stop.cfg]
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2022-11-02 More probing more problems
    [probe.cfg]
2022-11-02 Flip the fan pins again
    [btt-skr-pico.cfg]
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2022-11-04 Correct tower orientation - rotate CCW
    Rotate CCW. Clear calibration
    [printer.cfg, sensorless-homing.cfg]
2022-11-04 Correct sensorless homing rotation
    [sensorless-homing.cfg]
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2022-11-04 change stall guard to 52 all around
    [sensorless-homing.cfg]
2022-11-04 Move purge strip to upper left corner
    This mimics the behavior when the towers were rotated.
    [start-stop.cfg]
2022-11-04 Increase retraction to clear toolhead on Revo
    Revo manual says to pull back 18 instead of the 3 we were doing before.
    Increase purge volume accordingly.
    [printer.cfg, start-stop.cfg]
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2022-11-05 Decrease flow during purge to match max for 0.4n
    [start-stop.cfg]
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2022-11-06 Reset endstop phase cal
    [printer.cfg]
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2022-11-16 Correct pin for QGL probe
    [printer.cfg]
2022-11-16 Correct bed temp pin
    [printer.cfg]
2022-11-16 Correct pin, harder.
    [printer.cfg]
2022-12-11 integrate tap config with Mellow Fly SB2040 via CAN
    [bed_mesh.cfg, mainsail_klipper.cfg, printer.cfg]
2022-12-12 Correct pinouts
    Motors in the right spot, move stuff to sb2040
    [printer.cfg]
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2023-01-10 Correct Revo thermistor type
    [printer.cfg]
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2023-01-10 Correct nozzle parking location at rear
    [printer.cfg]
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2023-01-18 Split up config somewhat
    Add revo and mosquito magnum config
    Add beeper and songs
    Add resonance testing
    Add filament runout sensor
    [M600.cfg, M900.cfg, TEST_SPEED.cfg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]
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2023-01-26 Disable pause on runout due to flakey btt smartie
    [btt-smartie.cfg]
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2023-01-26 Move LED settings to appropriate areas
    Override qgl and g28
    [printer.cfg]
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2023-01-26 Reset LEDs after print completes
    [printer.cfg]
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2023-01-28 Fix QGL rename
    [printer.cfg]
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2023-02-10 Adaptive Mesh and Purge on Voronica
    Enable the Adaptive Mesh and Adaptive Purge macros from:
    https://github.com/kyleisah/Klipper-Adaptive-Meshing-Purging
    [Adaptive_Mesh.cfg, Adaptive_Purge.cfg, printer.cfg]
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2023-05-24 Add PID tune and thermistor config for slice
    [slice_mosquito_magnum.cfg]
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2023-05-24 Switch max heater power to 0.6
    Was triggering UPS overload
    [printer.cfg]
2023-05-24 Change PWM cycle time for heater to 60 Hz
    Supposed to stop light flickering, seems to make kitchen lights worse
    though.
    [printer.cfg]
2023-05-24 Change e-bay fans to controller type
    Bring noise level down.
    [printer.cfg]
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2023-05-24 Fix nozzle parking at end of print
    [printer.cfg]
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2023-10-01 Set up Mosquito with PT1000, move PID to main
    [printer.cfg, slice_mosquito_magnum.cfg]
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2023-10-02 Fix Pin definition for FAN1
    [spider_aliases.cfg]
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2023-10-05 Switch to 0.6 nozzle
    Add notes about difference in Z offset between the two nozzle sizes.
    [printer.cfg]
2023-10-07 Clean up configs
    Move menus out to separate file
    Clean up old comments
    [mainsail_klipper.cfg, menu.cfg, printer.cfg]
2023-10-07 Update lighting
    Fix homing effects
    Add LED flash on probe activation
    [led_effects.cfg, lighting.cfg, printer.cfg]
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2023-10-10 fix param name
    [printer.cfg]
2023-10-16 Decrease stallguard after optical endstop test
    [sensorless-homing.cfg]
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2023-10-16 Correct steppers
    [steppers.cfg]
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2023-10-16 Fix e_diag_pin def and cooling fans
    [btt-skr-pico.cfg]
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2023-10-21 Update baseline endstops for lerge
    attempting to combat z stretch after delta_calibrate
    [printer.cfg]
2023-10-22 Correct rotation distance
    [steppers.cfg]
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2023-11-03 Update A-B motor current based on spec sheet
    [printer.cfg]
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2023-11-08 Use FYSETC extruder
    Recalibrate rotation distance
    Reverse e_dir_pin
    [cr10-clone.cfg, steppers.cfg, tmc2209.cfg]
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2023-11-08 reverse btt smartie reset
    [start-stop.cfg]
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2023-12-01 Change fans around
    Pi fan to tinyfax aux1
    Rename skirt fans
    Add controller stepper fans
    [printer.cfg]
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2023-12-03 Correct display offset and visible lines
    [V0Display.cfg]
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2023-12-06 extended delta_calibrate w/glass bed and tower adj
    adjusted the Gamma (C) tower which was too high
    Noted that the aluminum bed had a bad warp, replaced with borosilicate
    glass.
    Re-ran extended calibration.
    [printer.cfg]
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2023-12-12 Fix beeper syntax
    [beeper.cfg]
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2023-12-14 Tune orbiter, speeds, resonance
    Ditch klippain, use the ShakeNTune module from it though.
    Fix up orbiter configuration - remove gear ratio, set microsteps correctly
    Tune max accels and speeds, 550 mm/s @ 18000 mm/s^s
    [bigtreetech-skr-pico-v1.0.cfg, ebb36.cfg, orbiter.cfg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]
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2024-01-01 Start bed heating before homing
    Speeds up startup times significantly.
    [bigtreetech-skr-pico-v1.0.cfg]
2024-01-01 Retract filament from meltzone at print end
    [bigtreetech-skr-pico-v1.0.cfg]
2024-01-01 Enable PWM on caselights
    Looks like the klipper expander does a better job of PWM than the mosfet board I was using on the BTT Pi.
    [klipper-expander.cfg]
2024-01-01 Enable object cancelling
    Allow object cancel to work by enabling object pre-processing in
    moonraker's file_manager configuration and adding the right config to
    the main printer.cfg
    [printer.cfg]
2024-01-01 Adjust endstop position
    reassembled bed during recent maintenance
    [printer.cfg]
2024-01-01 Add aux_fan for PLA cooling
    STL and config from:
    https://github.com/JackJack3231/V0-Auxiliary-Fan/
    Using FAN1 port on SKR Pico which was freed up during the CANBUS conversion.
    [aux_fan.cfg, printer.cfg]
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2024-01-04 home during calibrate offset and move to the center
    [StartupMacros.cfg]
2024-01-04 Add CANCEL_PRINT override
    split out common commands and logic from end_print to reuse in cancel_print
    [bigtreetech-skr-pico-v1.0.cfg]
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2024-02-05 Remove klipper expander
    SKR Pico Neopixel port isn't actually fried, just the on-board neopixel itself.
    Caselight now powered from the hotend mosfet.
    [bigtreetech-skr-pico-v1.0.cfg, printer.cfg]
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2024-02-24 Reset idle timeout to tr approved value
    [printer.cfg]
2024-02-24 fix up tradrack start stop
    [start_stop.cfg]
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2024-11-11 Correct belay sensor pins
    Had compression, needed to be tension.
    Pin Y-STOP is bad on this board, using PS-ON instead.
    [mmu_hardware.cfg, mmu_parameters.cfg]
2024-11-11 Use new interruptible heat soak macro in menu
    [menu.cfg]
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2024-11-11 Clean up stuff from start and stop
    Old tradrack variables just made configuration harder.
    [start_stop.cfg]
2024-11-11 Speed up bed mesh by changed z hop to 3 from 10
    [probe.cfg]
2024-11-11 Replace printed tap with CNC tap v2
    Different optical sensor with inverted logic from home-built one.
    [probe.cfg]
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2024-11-11 Change max extrude for smaller 0.25 nozzle
    Purge line wasn't working
    [orbiter.cfg]
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2024-11-11 Update Happy Hare
    Multiple updates of Happy Hare code. Migrate the CLEAN_NOZZLE from a custom macro definition to a variable hook definition since _MMU_POST_LOAD is read-only now.
    [blobifier.cfg, blobifier_hw.cfg, client_macros.cfg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]
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2024-11-11 Use built-in bed meshing
    No need for KAMP with the nozzle scrubber and purge buckets combined with the built-in Klipper adaptive mesh.
    [printer.cfg, start_stop.cfg]
2026-02-03 Re-add KAMP, misc fixes
    [KAMP_Settings.cfg, blobifier.cfg, dc_espooler.cfg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]
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2026-02-26 Organize active printer documentation
    - Rename voronica/doc/ to voronica/docs/ for consistency with hodad
    - Fix broken image paths in voronica README (missing images/ prefix)
    - Standardize both active printer READMEs with consistent sections:
    Overview, Modifications, Notes, Links, Procedures
    - Add hardware overview tables to both printer READMEs
    - Clean up root README with a proper spec comparison table
    - Fix typo in voronica README ("documentsion" -> "documentation")
    - Fix incorrect CLAUDE.md label in AGENTS.md directory tree
    https://claude.ai/code/session_019H2a24G9ktdcomYNZtESDF
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2026-03-04 chore(voronica): update config files post os update
    Refine crowsnest configuration comments, add mainsail.cfg reference, and update moonraker and printer configurations for improved clarity and organization
    [mainsail.cfg, printer.cfg]
